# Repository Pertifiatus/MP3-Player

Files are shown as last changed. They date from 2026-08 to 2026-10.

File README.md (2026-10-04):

# MP3-Player

A compact **DIY music player**, smaller than an iPod Touch, built around a Raspberry Pi Compute Module 4 on a custom PCB. It syncs your **YouTube Music** library straight to the device, no home server needed.

## Concept

- **Front:** round GC9A01 display for menus and navigation
- **Back:** monochrome SSD1306 OLED for music visualizations
- **Audio:** mainly Bluetooth A2DP, plus a 3.5 mm headphone jack (ES8388 codec)
- **Controls:** button box (SX1509 GPIO expander) + IMU (QMI8658A) for orientation and shake gestures
- **Power:** Li-ion battery, USB-C charging (RT9466) with an 80% charge limit, fuel gauge (MAX17048), soft power button
- **Lighting:** SK6812 status ring

## Hardware

| Part | Details |
|---|---|
| Compute | Raspberry Pi CM4 Lite Wireless (boots from microSD), on 2× Hirose mezzanine connectors |
| Power | TPS63020 buck-boost, RT9466 charger, MAX17048 fuel gauge |
| Audio | ES8388 codec over I2S |
| Displays | GC9A01 (SPI0), SSD1306 (SPI4) |
| PCBs | Main board + ButtonBox, designed in KiCad (`KiCad/Projekt 1`) |
| Case | Fusion 360 (`CAD/Player.f3z`) |

## Software (`Software/`)

Python on Raspberry Pi OS, running as systemd services:

| File | Purpose |
|---|---|
| `main.py` | Main UI loop (front display, buttons, IMU) |
| `player.py` | Playback |
| `sync_youtube.py` | YouTube Music library sync |
| `connectivity.py` | WiFi / Bluetooth connections |
| `ui_state.py`, `ui_render.py` | UI state machine and rendering |
| `buttonbox.py`, `qmi8658.py`, `es8388.py`, `max17048.py`, `rt9466.py` | Hardware drivers |
| `charge_control.py`, `power_button.py` | Charging logic and soft shutdown |
| `led_control.py`, `led_service.py` | Status ring LEDs |
| `setup_pi.sh`, `*.service`, `sdcard-boot-*` | Pi setup and boot configuration |
| `test_*.py` | Tests |

## Status

Work in progress. Board 2 boots reliably; the software bring-up and debugging of battery operation are ongoing. Detailed notes on hardware, pinout, `config.txt` and lessons learned are in [`CLAUDE.md`](CLAUDE.md) and [`Software/NOTES_FOR_PER.md`](Software/NOTES_FOR_PER.md).

## Repository structure

```
CAD/        Fusion 360 case
KiCad/      Main board + ButtonBox (schematics, PCB, 3D models)
Software/   Python application, drivers, services, tests
docs/       Design specs and plans (status ring, quick connect)
```

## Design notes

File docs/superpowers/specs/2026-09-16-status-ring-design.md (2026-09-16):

# Status-Ring: Akku + WLAN/Bluetooth am Displayrand

## Ziel

Akkustand (%), WLAN- und Bluetooth-Status sollen am runden Front-Display sichtbar
sein, ohne bestehenden Screen-Inhalt zu verdecken. Bisher liest `main.py` den
MAX17048 (Fuel Gauge) gar nicht - nur der separate `charge_control.py`-Service tut
das für die Ladelogik. WLAN/BT-Status existiert bereits in `ui_state`/`connectivity.py`,
ist aber nur in den WLAN/BT-Menüs sichtbar, nicht auf einen Blick.

## Sichtbarkeit (Settings-Toggle)

Neuer Eintrag unter Settings → Anzeige: **"Statusanzeige"** (choice, wie
`display.led_mode`), Werte `"home"` (Standard) / `"always"`:
- `"home"`: Ring nur auf dem Homescreen.
- `"always"`: Ring auf jedem Screen.

Technisch macht das kaum einen Unterschied, da der Ring in einem Rand-Bereich liegt,
den kein bestehender Screen aktuell nutzt (siehe unten) - der Toggle existiert rein,
weil der Nutzer das explizit so wollte (z.B. falls der Ring auf dem Now-Playing-Screen
optisch stören sollte).

## Visuelles Design (auf dem Home-Browser-Mockup abgestimmt und freigegeben)

Alle Werte in der 240×240-Koordinate des echten Displays (nicht die gezoomte
320px-Mockup-Darstellung). Ursprung/Formel: `x = 120 + r·cos(θ)`, `y = 120 + r·sin(θ)`,
θ in Grad, steigendes θ läuft am Bildschirm im Uhrzeigersinn.

**Radius/Ring liegt fix bei r=110** (nicht `ui_scale`-abhängig, wie `SAFE_R` eine
Hardware-Konstante) - äußerer Rand des 12px-Strichs landet bei r=116, also ~4px
Abstand zum physischen Bezel-Rand (r=120). Innerer Rand bei r=104 = identisch mit
`SAFE_R`, kollidiert also nicht mit vorhandenem Safe-Area-Inhalt.

1. **Akku-Slot**: Bogen von θ=-55° bis θ=+30° (85° Spannweite), Strichbreite 12px,
   `round`-Linecap an beiden Enden (klassische Pill-/Slot-Form).
   - Track: dunkelgrau (`#3a3a3c`, passt zu `GROUP_BG`-Familie).
   - Fill: Akzentfarbe (`ACCENT` = `#31d1a6`), von θ=-55° bis zum
     ladungs-proportionalen Punkt innerhalb der 85°-Spanne.
2. **WLAN-Punkt**: Kreis bei θ=+38°, Radius 6px (= halbe Strichbreite, gleiche
   optische Dicke wie der Slot).
3. **Bluetooth-Punkt**: Kreis bei θ=+46°, Radius 6px.
   - Abstand Slot-Ende↔WLAN-Punkt und WLAN-Punkt↔BT-Punkt jeweils ~3px zwischen den
     sichtbaren Kanten (Rundungen mit eingerechnet).
4. **Prozent-Text**: klein (~11px Font), nahe der oberen Kante neben dem Slot-Anfang
   (Richtwert (183, 16), siehe Hinweis unten zur Feinjustage).

**Drei Zustände pro Punkt** (WLAN und Bluetooth gleich kodiert, nur Farbe
unterschiedlich - Weiß für WLAN, Blau (`#0a84ff`, passt zu `CATEGORY_COLORS["connectivity"]`)
für Bluetooth):
- **Aus**: gedimmt gefüllt (`#48484a`, wie `_draw_toggle_pill`s Aus-Farbe).
- **An, nicht verbunden**: hohler Ring (`stroke`, kein `fill`) in der jeweiligen Farbe.
- **Verbunden**: voll gefüllt in der jeweiligen Farbe.

## Bekannter Feinjustage-Punkt (bewusst nicht jetzt gelöst)

Der Home-Screen-Header ("MINI-MUSIKPLAYER", zentriert bei y=36, nur wenn
`home_sel == 0`) kann sich mit dem Prozent-Text/Slot-Anfang überschneiden, je
nachdem wie breit der letter-spaced Header mit den echten DejaVu-Fonts tatsächlich
rendert (auf Windows/Arial lokal nicht exakt prüfbar, siehe bestehende Einschränkung
in `NOTES_FOR_PER.md`). Wird beim ersten Live-Test auf echter Hardware geprüft und
falls nötig verschoben (z.B. Prozent-Text ein paar Pixel tiefer) - kein Blocker für
die Implementierung.

## Datenanbindung

### Akkustand (neu für `main.py`)
- `main.py` bekommt eine eigene `MAX17048`-Instanz (gleiches I2C-Gerät, das auch
  `charge_control.py` als separater Prozess nutzt - kurze Einzel-Reads sind
  bus-seitig unproblematisch, kein gemeinsamer State nötig).
- Poll-Intervall: alle 30s (SOC ändert sich langsam, kein Grund häufiger zu lesen,
  gleiches Prinzip wie `charge_control.py`s eigener Poll-Zyklus).
- Fehlerfall (Gauge nicht erreichbar): wie beim IMU in `main()` behandeln -
  `try/except`, Feature fällt auf "kein Ring-Update" zurück statt zu crashen.

### WLAN/Bluetooth-Status (bereits vorhanden, nur neu zusammengeführt)
- **An/Aus**: `state.settings.get("connectivity", "wifi"/"bluetooth")` - existiert
  bereits.
- **Verbunden**: leichte, gedrosselte Polls (kein Shell-Aufruf pro Frame):
  - WLAN: `connectivity.wifi_known_connections()`, `any(n["connected"] for n in ...)`.
  - Bluetooth: `connectivity.bluetooth_known_devices()`, analog.
  - Intervall: alle 10s, gleiches Muster wie die bestehenden
    `WIFI_REDRAW_INTERVAL`/`BT_REDRAW_INTERVAL`-Konstanten in `main.py`.

## Rendering-Integration

Ein neuer `_draw_status_ring(img, draw, state)` in `ui_render.py`, aufgerufen aus
dem zentralen `render()`-Dispatcher (nicht in jeder einzelnen `render_*`-Funktion
dupliziert) - abhängig von `state.settings.get("display", "status_ring")`:
`"always"` → nach jedem Screen zeichnen, `"home"` → nur wenn
`state.screen == ui_state.SCREEN_HOME`.

## Testing

Neue Fälle in `test_ui_render.py` (bestehendes Muster: alle Screens/States
durchrendern, `py_compile`-Smoke-Test): Ring bei 0%/50%/100% Akku und allen
3×3-Kombinationen WLAN/BT-Zustand rendern, keine Exception, Werte bleiben innerhalb
des 240×240-Bilds.

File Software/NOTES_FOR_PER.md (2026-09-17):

## TODO: LED-Indicator-Flash übergangsweise deaktiviert (17.09.2026)

Beim Durchgehen der LED-Settings festgestellt: `led_service.py` läuft aktuell
gar nicht auf dem Gerät (kein systemd-Unit, kein manueller Prozess) - die
LED-Einstellungen (An/Aus, Modus, Farbe, Helligkeit) schreiben zwar korrekt in
`settings.json`, steuern aber noch keine echte Hardware an. Bevor der Service
eingerichtet wird, kam eine wichtige Korrektur von Per: **aktuell sind nur 3
LEDs verkabelt**, nicht die ursprünglich angenommenen 9 (6 Hauptboard + 3
ButtonBox) - `led_control.NUM_LEDS` entsprechend auf 3 korrigiert. Mapping:
Index 0 = Play/Pause, 1 = Shuffle, 2 = Stop (je eine feste Pro-Button-LED, kein
generischer Streifen).

Dadurch hat `led_service.py`s Encoder-Skip/Volume-Cue (kurzer Farbblitz beim
Umschalten auf der Playing-Screen, ausgelöst über `main.py`s
`settings.set("led", "indicator", ...)`) keine LED mehr, die er benutzen
könnte - `INDICATOR_LED_INDEX = 4` lag schon für die alte 9er-Annahme am
oberen Rand, mit nur 3 LEDs (Index 0-2) ist er komplett out of range und hätte
beim ersten Auslösen gecrasht (`flash_indicator()` schreibt auf
`self._pixels[index]`).

**Übergangsweise auskommentiert** in `led_service.py` (`INDICATOR_LED_INDEX`
und der Aufruf von `flash_indicator()` in der Poll-Loop, mit `ponytail:`-
Kommentar an der Stelle) - `main.py` schreibt weiterhin harmlos in
`settings["led"]["indicator"]`, nur liest aktuell niemand mehr davon.

**TODO sobald mehr LEDs verlötet sind (oder eine der 3 bestehenden dafür
freigegeben wird):** Cue-Flash wieder aktivieren - entweder auf einer neuen,
freien LED-Nummer, oder bewusst auf einer der 3 Button-LEDs (z.B. Play/Pause,
da die während des Encoder-Drehens meist nicht gerade blinkt) mitlaufen lassen.
Nicht vergessen: `led_service.py` braucht sowieso noch einen echten
systemd-Unit (root, PWM+DMA) - bis dahin ist das ganze LED-Feature ohnehin nur
Settings-UI ohne sichtbare Wirkung.

## Nachtrag: UI-Groesse überarbeitet - echtes Reflow statt Zoom (12.09.2026, fünfter Durchgang)

Kein Pi-Zugriff, rein lokal (Windows) an `ui_render.py` gearbeitet + Logik-/Layout-
Smoketest (`test_ui_render.py`, neu) - **noch nicht auf echter Hardware/mit den
echten DejaVu-Fonts visuell verifiziert**, bitte beim nächsten Boot durch alle 5
UI-Groesse-Stufen auf Home/Bibliothek/Playlist/Settings klicken.

Auslöser: Feedback, dass "UI Scale" bisher nur pixelig rein-/rauszoomt statt bei
kleineren Stufen den gewonnenen Platz für mehr Inhalt zu nutzen, dass generell zu
viel Text abgeschnitten wird und dass die Ränder unnötig dick sind.

**Kompletter Umbau von `_apply_ui_scale`** (der alte Zoom-aufs-fertige-Bild-Ansatz,
siehe Nachtrag weiter unten - jetzt entfernt) **zu echter Layout-Skalierung**: Der
`scale`-Faktor fließt jetzt direkt in Fontgrößen, Row-Heights, Icon-Größen und
Innenabstände in `_render_nav_list`, `render_settings_detail` etc. ein, statt nur
das fertige 240×240-Bild zu croppen/skalieren. Effekt: bei kleiner UI-Groesse
passen durch kleinere Rows tatsächlich mehr Einträge in denselben runden Safe-Bereich
(gemessen: Playlist-Liste zeigt bei Stufe 1 eine dritte teilsichtbare Zeile, die bei
Stufe 3 nicht mehr da ist), bei größerer UI-Groesse werden Fonts/Rows größer
(besser lesbar), dafür passt weniger gleichzeitig auf den Screen - erwarteter
Trade-off, kein Bug. Fonts werden jetzt lazy per `(key, scale)` geladen und gecacht
(`ui_render._font`), nicht mehr als fixe Modul-Konstanten.

Nebenbei allgemein die Innenabstände verkleinert (Header-Padding, Icon/Text-Abstände
in den Listen, Settings-Card-Ränder), damit generell mehr vom runden Screen genutzt
wird, unabhängig von der UI-Groesse-Stufe. **SAFE_R (der physische Rundbezel-Wert)
wurde bewusst NICHT verändert** - das ist eine Hardware-Grenze, keine Stil-Vorgabe.

**Echter Bug beim Umbau gefunden und gefixt:** `render_settings_detail` ging bisher
davon aus, dass eine Settings-Kategorie immer komplett auf den Screen passt (stimmte
zufällig bei allen aktuellen Kategorien bei Stufe 3). Sobald Rows bei größeren
UI-Groesse-Stufen mitwachsen, ragte die Karte für Kategorien mit mehr Einträgen
(z.B. "LED", 4 Einträge) über den unteren Bildrand hinaus - `draw.rounded_rectangle`
crashte dabei sogar hart (`x1 must be greater than or equal to x0`), weil die Karte
an dem Punkt schon komplett außerhalb des runden Safe-Bereichs lag. Fix: die Liste
scrollt jetzt um die aktuelle Auswahl herum (gleiches Prinzip wie die Home/Bibliothek-
Listen), inkl. kleiner Auf/Ab-Pfeil-Indikatoren, wenn oben/unten noch mehr Einträge
verborgen sind. `test_ui_render.py` rendert alle Screens bei allen 5 Stufen durch und
hätte diesen Crash sofort gefangen.

`UI_SCALE_STEPS`-Werte dabei leicht verbreitert (0.75-1.3 statt 0.82-1.25), damit der
jetzt echte Skalierungseffekt sichtbarer ist. Stufe 3 bleibt exakt 1.0 = alle Pixel-
Konstanten im File wie ursprünglich getunt, unverändertes Verhalten für den Standard-
Fall.

---

## Nachtrag: ~1fps-Refresh + Encoder-Aussetzer (12.09.2026, vierter Durchgang)

Du warst kurz weg, ich hatte keinen Pi-Zugriff. Beides unten ist lokal
simuliert/getestet (reine Logik + Timing-Messung auf meinem Windows-Rechner) und
per Recherche im offiziellen Adafruit_Blinka_Displayio-Quellcode auf GitHub
abgesichert — **aber noch NICHT auf echter Hardware verifiziert**. Bitte beim
nächsten Boot beides gezielt gegentesten (Navigation durchklicken + Encoder in
beide Richtungen mehrfach drehen).

### 1fps-Fix: `push_frame()` → `FrameSink` in [main.py](main.py)

Root Cause gefunden, nicht nur vermutet: Ich habe den tatsächlichen Quellcode von
`Adafruit_Blinka_Displayio` auf GitHub geprüft. `displayio.OnDiskBitmap._get_pixel()`
liest **jeden einzelnen Pixel per eigenem Datei-`seek()`+`read()` vom Datenträger**,
und das passiert innerhalb der (ebenfalls reinem Python, pixel-für-pixel-Schleife)
Bildkomposition in `_tilegrid.py`. Die alte `push_frame()` hat bei **jedem** Redraw
ein komplett neues `OnDiskBitmap` aus einer frisch gespeicherten Datei gebaut — macht
bei 240×240 = 57.600 Pixel pro Frame theoretisch 57.600 Einzel-Dateizugriffe. Das
erklärt die ~1fps ziemlich genau (das reine `ui_render()` selbst braucht lokal
gemessen nur ~20ms/Frame, ist also nicht der Flaschenhals).

Fix: `FrameSink`-Klasse baut `Bitmap`/`TileGrid`/`Group` **einmalig** beim Start
(nicht mehr pro Frame neu), hält sie im RAM, und jeder Redraw schreibt die
RGB565-Pixel direkt in das bestehende `Bitmap` — kein Datei-Umweg mehr. Farbkonvertierung
RGB→RGB565 läuft vektorisiert über numpy (schnell), nur das eigentliche Schreiben in
den `Bitmap` läuft noch pixelweise über `bitmap[i] = value` (das ist die einzige
öffentlich dokumentierte Schreib-API, die ich im Quellcode bestätigt gefunden habe —
lokal gemessen ~5-7ms für 57.600 Pixel auf einem schnellen PC, auf dem CM4 evtl.
30-100ms, aber selbst das wäre um Größenordnungen schneller als der alte
Platten-Umweg).

**Falls es auf dem Pi immer noch spürbar hakt:** nächster Hebel wäre, `displayio`
für die Pixel-Übertragung ganz zu umgehen und die RGB565-Bytes direkt über den
SPI-Bus zu schreiben (wie z.B. `luma.lcd` es für andere Displays macht) — das ist ein
größerer Umbau, den ich nicht blind schreiben wollte ohne die aktuelle
Verbesserung erst mal live zu sehen.

### Encoder-Fix: Debounce-State-Machine in [buttonbox.py](buttonbox.py)

Die alte `_QUAD_TABLE`-Logik hat bei **jedem einzelnen Viertelschritt** gefeuert und
hatte keinerlei Prellschutz auf den Encoder-Leitungen (nur Buttons hatten
`DEBOUNCE_S`). Recherche dazu (siehe Quellenliste unten) bestätigt: genau das ist
eine bekannte Fehlerklasse bei I2C-gepollten Encodern — ein Prellen auf nur einer der
beiden Leitungen (A oder B) kann in der einfachen Tabelle als gültiger Übergang in
die **falsche** Richtung interpretiert werden, was zur gemeldeten
richtungsabhängigen Unzuverlässigkeit passt.

Neue Logik in `decode_encoder_step()`: läuft dem gültigen Gray-Code-Zyklus
(00→01→11→10→00) als Zähler entlang und feuert erst nach einem **vollständigen**,
in sich konsistenten 4-Schritt-Durchlauf (= ein Klick am Rastpunkt). Prellen
(Sprung zurück zum vorherigen Wert) und übersprungene Zwischenzustände (bei zu
langsamer Poll-Schleife) verwerfen jeweils nur den einen zweideutigen Schritt,
lösen aber keine Fehlauslösung mehr aus. Mit 8 Tests in
[test_buttonbox.py](test_buttonbox.py) durchgetestet (saubere CW/CCW-Klicks,
Prellen an verschiedenen Stellen der Sequenz, übersprungene Zustände) — alle grün.

**Nebeneffekt, bitte beachten:** Die alte Logik hat pro physischem Klick (4
Viertelschritte) theoretisch 4x ausgelöst, die neue genau 1x pro Klick. Falls sich
der Encoder jetzt "zu träge" anfühlt (mehr Drehung nötig pro Menüschritt als
gewohnt), sag mir das — dann justiere ich `DETENT_STEPS` in `buttonbox.py`.

Da der 1fps-Bug die komplette Poll-Schleife bei jedem Redraw für hunderte
Millisekunden blockiert hat, dürfte der FrameSink-Fix allein schon einen Großteil
der Encoder-Aussetzer beheben (verpasste Zwischenzustände durch zu seltenes
Pollen) — die Debounce-Fix behebt zusätzlich die richtungsabhängigen Fehlauslösungen
durch Prellen, die auch bei schneller Poll-Schleife noch auftreten könnten.

## Nachtrag: UI-Größe-Einstellung (11.09.2026, dritter Durchgang)

**Überholt, siehe Nachtrag ganz oben (12.09.2026, fünfter Durchgang)** - der
Zoom-Ansatz unten wurde durch echte Layout-Skalierung ersetzt. Als Historie
stehen gelassen.

Neuer Settings-Punkt unter Anzeige: "UI-Groesse" (Stepper 1-5, Standard 3=100%).
Implementiert als **Zoom aufs fertig gerenderte Bild** (`_apply_ui_scale` in
`ui_render.py`), nicht als Skalierung jeder einzelnen Pixelzahl im Code — deutlich
weniger Code, kein Risiko dass irgendwo eine feste Zahl vergessen wird und Elemente
überlappen. Trade-off: bei größeren Stufen wird das Bild reingezoomt (Ränder werden
abgeschnitten, wie bei jedem Digital-Zoom), bei kleineren rausgezoomt (schwarzer Rand
rundrum). Lokal bei allen 5 Stufen getestet, sieht sauber aus. Logik-Tests weiterhin
grün (nur ein neuer Settings-Eintrag, State-Machine sonst unverändert).

## Nachtrag: Apple/iOS-Redesign (11.09.2026, zweiter Durchgang)

Auf Wunsch komplett neuer visueller Look für `ui_render.py` (State-Machine/Logik
unverändert, nur die Optik):
- Echtes Schwarz als Hintergrund statt Dunkelgrau, iOS-System-Grau-Palette für Text
- Settings-Kategorien haben jetzt knallige, iOS-typische Icon-Farben (Anzeige=Orange,
  LED=Gelb, Verbindung=Blau, Sync=Türkis, Bewegung=Rot, Über=Grau) statt einheitlichem
  Grau
- Settings-Detail-Screens sind jetzt eine einzelne abgerundete Karte mit
  Trennlinien zwischen den Zeilen (iOS "Inset Grouped List"), statt einzelner Pillen
  pro Zeile
- Now-Playing hat jetzt einen echten Frosted-Glass-Effekt (geblurrter,
  abgedunkelter Ausschnitt hinter einer abgerundeten Pille) für die
  Play/Pause-Anzeige, statt nur freistehendem Text
- Icon-Badges sind jetzt "Squircle"-artig (großzügigerer Eckenradius) statt einfacher
  abgerundeter Quadrate

Alles wieder lokal gerendert + die 8 Logik-Tests laufen weiterhin durch (an der
State-Machine wurde nichts geändert). Gleiche Einschränkung wie vorher: nie auf
echter Hardware/DejaVu gesehen.

---

# Notizen zum UI/Interface-Ausbau (11.09.2026, während du weg warst)

Pi war die ganze Zeit aus — nichts davon ist auf echter Hardware getestet. Ich habe
alle Screens lokal mit PIL gerendert (Arial statt DejaVu als Ersatz-Font, da DejaVu
hier auf Windows nicht verfügbar war) um Layout/Lesbarkeit zu prüfen, und dabei ein
paar echte Bugs gefunden und gefixt (siehe unten). Alle Python-Dateien sind
syntax-geprüft (`py_compile`), aber der komplette Hardware-Pfad (Buttons, IMU, beide
Displays, LEDs) läuft zum ersten Mal beim nächsten Boot — bitte Schritt für Schritt
testen, nicht direkt alles auf einmal.

## Neue/geänderte Dateien in `Software/`

| Datei | Zweck |
|---|---|
| `ui_state.py` | State Machine: Home, Bibliothek, Playlist, Now-Playing, Settings (Kategorien + Detail), Sync-Login, Sync-Progress |
| `ui_render.py` | PIL-Rendering für alle Screens, inkl. rotierender Cover-Art-Platte mit Tonarm |
| `main.py` | Event-Loop: ButtonBox + IMU (Bewegungs-Features) + Display |
| `qmi8658.py` | IMU-Treiber als wiederverwendbares Modul (vorher nur Einweg-Testskript) |
| `led_control.py` | SK6812-Ansteuerung (Presets, Modi) |
| `led_service.py` | **Separater** root-Prozess, der `settings.json` beobachtet und die LEDs ansteuert |
| `settings.py` | Persistente Einstellungen (JSON-Datei) |
| `sync_youtube.py` | YouTube-Device-Flow-Login (echt implementiert) + simulierter Sync (Platzhalter) |

## Was garantiert noch nicht getestet ist — bitte in dieser Reihenfolge

1. **`python3 main.py` auf dem Pi starten** (braucht laufendes Front-Display + ButtonBox +
   QMI8658A — alles einzeln schon mal verifiziert, aber nie zusammen in einer Schleife).
2. Falls Fehler beim Start: `adafruit-blinka` + `adafruit-circuitpython-neopixel` sind
   evtl. noch nicht installiert (`pip3 install --break-system-packages
   adafruit-circuitpython-neopixel`) — nur für `led_control.py`/`led_service.py` nötig,
   `main.py` selbst importiert das nicht direkt.
3. `led_service.py` **braucht `sudo`** (PWM/DMA für die LEDs) — separat testen:
   `sudo python3 led_service.py`, dann in `settings.json` `led.enabled` auf `true`
   setzen und schauen ob die LEDs reagieren.

## Bewusste Design-Entscheidungen (getroffen, nicht mehr offen)

- **Stop-Taste = "Zurück"** in allen Menüs, zusätzlich "echtes Stop" (setzt Now-Playing
  zurück auf Home) wenn man sie im Now-Playing-Screen drückt.
- **Encoder-Drehen im Now-Playing-Screen = Track vor/zurück** (nicht Lautstärke — dafür
  gibt's aktuell keinen dedizierten Regler, siehe offene Frage unten).
- **Settings sind in 6 Kategorien** (Anzeige, LED, Verbindung, Sync, Bewegung, Über)
  organisiert, nicht eine lange flache Liste — bei einem 240px-Rundbildschirm sonst
  schnell unübersichtlich.
- **Icons als Buchstaben-Badges** (A/L/V/S/B/i) statt Symbol-Glyphen für die
  Settings-Kategorien — ich hatte erst Unicode-Symbole (☀ ✦ ⚡ ↻ ↕ ℹ) probiert, aber
  mehrere davon fehlen sogar in Arial (einem sehr breit unterstützten Font). Nur ♪
  und ⚙ sind aus einem früheren Live-Test auf dem echten Pi/DejaVu bestätigt sicher,
  alles andere Risiko wurde durch ASCII/Buchstaben ersetzt. **Bitte beim ersten Live-Test
  trotzdem kurz schauen ob irgendwo ein Kästchen (☐) statt einem Zeichen auftaucht** —
  falls ja, sag mir wo, dann tausche ich das gezielt aus.
- **Sync-Backend ist simuliert** (`sync_youtube.sync_library()` erzeugt Fake-Fortschritt
  über 8 Demo-Tracks) — die UI drumherum (Fortschrittsbalken, TV-Code-Screen) ist aber
  vollständig fertig und funktional, nur der eigentliche Download/ytmusicapi/yt-dlp/ffmpeg-Teil
  fehlt noch (siehe "Braucht deine Mitarbeit" unten).
- **LED-Kette läuft als separater root-Prozess** (`led_service.py`), nicht im
  Haupt-UI-Skript — vermeidet, dass die ganze UI (Display/Buttons/IMU) als root laufen
  muss, nur weil die LEDs PWM+DMA-Zugriff brauchen.

## Bewegungssensor-Features ("coole Sachen" mit dem Accelerometer)

Umgesetzt (in `main.py` / `apply_motion_features`):
- **Schütteln = Shuffle**: kräftige Bewegung (|Beschleunigung| > 2.2g) während
  Now-Playing überspringt zufällig vor/zurück und aktiviert die Shuffle-Anzeige.
- **Umdrehen = Pause**: wenn `orientation()` "z-" liefert (siehe Achsen-Warnung unten)
  und gerade etwas läuft, wird automatisch pausiert.

**Nicht umgesetzt, nur als Setting vorhanden (tut noch nichts):**
- **Auto-Display-Wechsel** (vorne/hinten je nach Ausrichtung) — der Setting-Toggle
  existiert in den Einstellungen, ist aber noch nicht verdrahtet. Grund: das würde
  bedeuten, das Rück-Display (SSD1306/luma) aus derselben Event-Loop wie das
  Front-Display zu steuern — das ist eine echte Architektur-Erweiterung
  (zwei Displays gleichzeitig koordinieren), die ich nicht blind bauen wollte ohne
  das live zu sehen. Wenn du zurück bist, können wir das als nächsten Schritt angehen.

**⚠️ Wichtig — Achsen-Mapping ist geraten, nicht verifiziert:** `orientation()` in
`qmi8658.py` gibt einfach die Achse zurück, die am nächsten an ±1g liegt (z.B. "z-").
Ich weiß nicht, welche physische Seite (vorne/hinten) das tatsächlich bedeutet — das
hängt davon ab, wie der QMI8658A-Chip auf der Platine liegt. **Bitte beim ersten Test:
Board flach hinlegen (Vorderseite nach oben), `python3 qmi8658.py` laufen lassen und
schauen welche Achse/Vorzeichen ausgegeben wird, dann das Gleiche mit Rückseite nach
oben — danach sag mir die beiden Werte, dann stelle ich `"z-"` in `apply_motion_features`
korrekt ein** (aktuell nur geraten, könnte auch falsch rum sein oder eine andere Achse
sein).

## Fragen, die ich nicht beantworten konnte (brauchen deine Entscheidung)

1. **LED-Kettenlänge:** `led_control.py` geht von 9 LEDs aus (6 Hauptplatine + 3
   ButtonBox, angenommen in Reihe). Nicht anhand des PCB-Layouts verifiziert — falls
   falsch, `NUM_LEDS` in `led_control.py` anpassen.
2. **SK6812MINI-E: RGB oder RGBW?** Ich bin von reinem RGB ausgegangen (Standard für
   die "MINI-E"-Variante). Falls es tatsächlich RGBW ist, braucht `neopixel.NeoPixel(...)`
   einen zusätzlichen `pixel_order=neopixel.GRBW`-Parameter.
3. **Lautstärke-Regelung:** Es gibt aktuell keinen UI-Weg die Lautstärke zu ändern
   (Encoder ist für Track-Skip belegt). Optionen für später: langes Drücken des
   Encoders = Lautstärke-Modus, oder ein Settings-Eintrag, oder Shuffle-Taste
   umwidmen. Sag mir was du willst.
4. **Auto-Sleep-Verhalten:** Der Settings-Eintrag "Auto-Aus" (Display-Standby nach
   X Sekunden Inaktivität) existiert als Einstellung, ist aber in `main.py` noch
   nicht tatsächlich verdrahtet (Backlight wird nirgends automatisch ausgeschaltet).
   Soll das den Backlight-Pin einfach dimmen/ausschalten, oder den ganzen
   Displayinhalt auf schwarz setzen?

## YouTube-Sync / TV-Setup — was noch fehlt

`sync_youtube.py` implementiert den **echten** Google-OAuth-Device-Flow (der
Standard-Mechanismus für TV/Limited-Input-Geräte: Code + URL anzeigen, User gibt den
Code auf Handy/PC ein, wir pollen bis bestätigt). Das ist kein Fake — das ist echtes,
funktionierendes Protokoll, sobald du Zugangsdaten hast.

**Was du dafür brauchst, bevor das erste Mal ein echter Login klappt:**
1. In der Google Cloud Console ein Projekt anlegen.
2. OAuth-Consent-Screen einrichten (reicht im "Testing"-Modus für privaten Gebrauch).
3. "YouTube Data API v3" aktivieren.
4. Unter Credentials einen OAuth-Client vom Typ **"TVs and Limited Input devices"**
   anlegen.
5. Die `client_id`/`client_secret` in eine neue Datei `Software/youtube_credentials.json`
   eintragen (Format steht im Docstring von `sync_youtube.py` oben) — **diese Datei
   NICHT committen**, sie ist noch nicht in `.gitignore`, das sollte ich/du noch
   ergänzen sobald die Datei existiert.

**Danach fehlt noch (nicht implementiert, nur die UI-Hülle steht):**
- Echte Bibliotheks-Abfrage über `ytmusicapi` (aktuell nicht mal als pip-Paket
  installiert).
- Download über `yt-dlp` + Remux über `ffmpeg`.
- Der WLAN/Metered-Check in `wifi_ok_for_sync()` ist aktuell ein Stub der immer
  `True` zurückgibt — müsste die echte Heim-SSID kennen und `nmcli` abfragen.

Das ist bewusst so gelassen — echtes Downloaden ohne deine OAuth-Zugangsdaten kann ich
eh nicht testen, aber die komplette UI drumherum (Code anzeigen, auf Bestätigung
warten, Fortschrittsbalken) ist fertig und sollte schon mit den echten Zugangsdaten
funktionieren, auch ohne dass der eigentliche Download-Teil schon existiert.

## Kleinere Bugs, die der lokale Test aufgedeckt hat (schon gefixt)

- `_render_nav_list` griff über einen privaten PIL-internen Pfad (`draw._image`) auf
  das Bild zu, um Cover-Art einzufügen — sauber gefixt, `img` wird jetzt explizit
  durchgereicht.
- Zwei Aufrufstellen von `_render_nav_list` hatten die alte Funktionssignatur nach
  einer Änderung nicht mitbekommen (`render_settings_root` u.a.) — hätte beim ersten
  Öffnen der Einstellungen sofort einen Crash gegeben.
- Lange Titel/Untertitel liefen über den Bildschirmrand hinaus statt abgeschnitten zu
  werden — Ellipsis-Kürzung ergänzt (wie im `beispiel.html`-Original).
- `state.shuffle` wurde in `ui_render.py` referenziert aber nie in `UIState.__init__`
  deklariert — hätte beim ersten Now-Playing-Aufruf gecrasht.

## Nicht getestet, aber nicht offensichtlich riskant

- Die hier vorhergesagte Performance-Sorge zum BMP-Datei-Umweg hat sich bestätigt
  (~1fps live gemeldet) — siehe "Nachtrag: ~1fps-Refresh + Encoder-Aussetzer" ganz
  oben in dieser Datei für Root Cause + Fix.

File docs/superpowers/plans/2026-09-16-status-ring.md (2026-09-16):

# Status-Ring (Akku + WLAN/Bluetooth) Implementation Plan

> **For agentic workers:** REQUIRED SUB-SKILL: Use superpowers:subagent-driven-development (recommended) or superpowers:executing-plans to implement this plan task-by-task. Steps use checkbox (`- [ ]`) syntax for tracking.

**Goal:** Show battery %, WLAN status and Bluetooth status as a ring hugging the round front-display's outer bezel margin, controllable via a new Settings toggle (Home-only vs. every screen).

**Architecture:** A pure-rendering function (`ui_render._draw_status_ring`) draws the ring onto whatever image `ui_render.render()` already produced, using three new plain fields on `UIState` (`battery_pct`, `wifi_connected`, `bt_connected`) that `main.py` refreshes on a slow poll cycle (30s battery, 10s WLAN/BT), mirroring the existing throttled-poll pattern already used for motion/BT/WiFi redraws in `main.py`.

**Tech Stack:** Python 3, PIL/Pillow (`ImageDraw.arc`/`ellipse`), existing `max17048.MAX17048` + `connectivity.py` drivers.

## Global Constraints

- Spec: `docs/superpowers/specs/2026-09-16-status-ring-design.md` - all pixel constants below (radius, angles, colors) are copied verbatim from there.
- The ring does **not** scale with `ui_scale` (fixed hardware-margin element, same reasoning as `ui_render.SAFE_R`).
- No new pip dependencies - only stdlib `math` (already imported in `ui_render.py`) and the existing `max17048`/`connectivity` modules.
- Every new pure-logic/rendering piece gets a test runnable with `python3 test_*.py` on a normal dev machine (no hardware) - matches this project's existing convention (see `test_ui_state.py`, `test_ui_render.py`). `main.py`'s hardware-loop wiring itself has no existing tests anywhere in this codebase (confirmed: no `test_main.py`) - that task ends in a manual on-device verification instead, consistent with how every other `main.py` change in this project's history (see `Software/NOTES_FOR_PER.md`) was verified.

---

### Task 1: "Statusanzeige" setting + visibility rule

**Files:**
- Modify: `Software/settings.py:7-12` (add default)
- Modify: `Software/ui_state.py` (add `SETTINGS_ITEMS["display"]` entry + `UIState.status_ring_visible()`)
- Test: `Software/test_ui_state.py`

**Interfaces:**
- Consumes: `Settings.get`/`Settings.set` (existing, unchanged), `UIState.screen`, `ui_state.SCREEN_HOME` (existing).
- Produces: `UIState.status_ring_visible(self) -> bool` - used by Task 2's `ui_render.render()` and Task 3's `main.py` dirty-flag logic.

- [ ] **Step 1: Write the failing test**

Add to `Software/test_ui_state.py` (near `test_choice_cycles`, same style):

```python
def test_status_ring_visible_depends_on_setting_and_screen():
    s = make_state()
    s.settings.set("display", "status_ring", "home")
    s.screen = ui_state.SCREEN_HOME
    assert s.status_ring_visible()
    s.screen = ui_state.SCREEN_LIBRARY
    assert not s.status_ring_visible()

    s.settings.set("display", "status_ring", "always")
    assert s.status_ring_visible()
    s.screen = ui_state.SCREEN_HOME
    assert s.status_ring_visible()

def test_status_ring_setting_cycles_via_settings_detail():
    s = make_state()
    s.settings.set("display", "status_ring", "home")
    s.settings_category = "display"
    idx = next(i for i, it in enumerate(ui_state.SETTINGS_ITEMS["display"]) if it["key"] == "status_ring")
    s.settings_detail_sel = idx
    s.settings_detail_activate()
    assert s.settings.get("display", "status_ring") == "always"
    s.settings_detail_activate()
    assert s.settings.get("display", "status_ring") == "home"
```

- [ ] **Step 2: Run test to verify it fails**

Run: `cd Software && python3 test_ui_state.py`
Expected: `AttributeError: 'UIState' object has no attribute 'status_ring_visible'` (or `KeyError: 'status_ring'` if it gets that far first)

- [ ] **Step 3: Add the setting default**

In `Software/settings.py`, inside `DEFAULTS["display"]` (currently lines 8-12):

```python
    "display": {
        "brightness": 3,     # 1-5, drives GC9A01 backlight PWM (GPIO13)
        "auto_sleep_s": 30,  # 0 = never sleep
        "ui_scale": 3,       # 1-5, index into ui_render.UI_SCALE_STEPS
        "status_ring": "home",  # "home" or "always" - see ui_render._draw_status_ring
    },
```

- [ ] **Step 4: Add the declarative settings-menu entry and the visibility method**

In `Software/ui_state.py`, inside `SETTINGS_ITEMS["display"]` (the list that currently ends with the `auto_sleep_s` choice entry), append:

```python
        {"key": "status_ring", "label": "Statusanzeige", "type": "choice",
         "choices": [("home", "Nur Home"), ("always", "Ueberall")]},
```

Add a method on `UIState` (near the other small helpers, e.g. right after `toggle_encoder_mode`'s class or anywhere inside `class UIState:` - place it right after `__init__`):

```python
    def status_ring_visible(self):
        return self.settings.get("display", "status_ring") == "always" or self.screen == SCREEN_HOME
```

- [ ] **Step 5: Run test to verify it passes**

Run: `cd Software && python3 test_ui_state.py`
Expected: `... 23 tests passed` (one more than the previous count - all `OK`, no failures)

- [ ] **Step 6: Commit**

```bash
git add Software/settings.py Software/ui_state.py Software/test_ui_state.py
git commit -m "Add Statusanzeige (status-ring visibility) setting"
```

---

### Task 2: `_draw_status_ring` rendering + dispatcher integration

**Files:**
- Modify: `Software/ui_state.py` (three new `UIState.__init__` fields)
- Modify: `Software/ui_render.py` (new constants, `_ring_point`, `_draw_status_dot`, `_draw_status_ring`, `render()` change)
- Test: `Software/test_ui_render.py`

**Interfaces:**
- Consumes: `UIState.status_ring_visible()` (Task 1), `UIState.settings.get("connectivity", "wifi"/"bluetooth")` (existing), `ui_render.ACCENT`/`TEXT`/`DIM`/`CATEGORY_COLORS` (existing), `ui_render._text_centered`/`_font` (existing).
- Produces: `UIState.battery_pct` (float 0-100 or `None`), `UIState.wifi_connected` / `UIState.bt_connected` (bool) - Task 3 sets these from real hardware polls. `ui_render._draw_status_ring(draw, state)` - not called directly by Task 3, only indirectly via `ui_render.render()`.

- [ ] **Step 1: Write the failing test**

Add to `Software/test_ui_render.py` (new top-level test function, same file, same style as `test_all_screens_render_at_every_scale`):

```python
def test_status_ring_renders_without_crashing():
    for battery_pct in (None, 0, 1, 50, 100, 104):  # 104: gauge over-reads slightly past 100, see max17048.py
        for wifi_on, wifi_connected in ((False, False), (True, False), (True, True)):
            for bt_on, bt_connected in ((False, False), (True, False), (True, True)):
                s = make_state()
                s.battery_pct = battery_pct
                s.wifi_connected = wifi_connected
                s.bt_connected = bt_connected
                s.settings.set("connectivity", "wifi", wifi_on)
                s.settings.set("connectivity", "bluetooth", bt_on)

                s.settings.set("display", "status_ring", "home")
                _assert_frame(ui_render.render(s))  # SCREEN_HOME - ring drawn

                s.screen = ui_state.SCREEN_LIBRARY
                _assert_frame(ui_render.render(s))  # "home" mode, not home - ring skipped

                s.settings.set("display", "status_ring", "always")
                _assert_frame(ui_render.render(s))  # "always" mode - ring drawn on library too
```

- [ ] **Step 2: Run test to verify it fails**

Run: `cd Software && python3 test_ui_render.py`
Expected: `AttributeError: 'UIState' object has no attribute 'battery_pct'` (test file sets it before first render, so this fires immediately)

- [ ] **Step 3: Add the three state fields**

In `Software/ui_state.py`, inside `UIState.__init__`, right after the existing `self.imu = None` line:

```python
        self.battery_pct = None  # 0-100 or None (gauge unavailable/not yet read); set by main.py from MAX17048
        self.wifi_connected = False  # set by main.py from connectivity.wifi_known_connections()
        self.bt_connected = False  # set by main.py from connectivity.bluetooth_known_devices()
```

- [ ] **Step 4: Run test to verify it now fails later (rendering not implemented yet)**

Run: `cd Software && python3 test_ui_render.py`
Expected: passes through field access now, but `render()` itself doesn't yet call any ring code, so this actually **passes already at this point** (nothing crashes - `render()` doesn't touch the new fields yet). That's expected: this step only proves the state fields exist. The ring behavior (mode="home" hides on Library) isn't asserted by pixel content in this test, only crash-freedom, so it can't fail here - proceed to Step 5 regardless.

- [ ] **Step 5: Implement `_draw_status_ring` and wire it into `render()`**

In `Software/ui_render.py`, add these module-level constants right after the existing `SAFE_R = 104` block (after `CARD_MAX_Y`'s definition, before `_header`):

```python
# --- status ring (battery + WLAN/BT) -----------------------------------------
# Fixed hardware-margin element, like SAFE_R - does NOT scale with ui_scale.
# Sits between SAFE_R (104) and the physical bezel (r=120): outer edge at
# RING_R + RING_WIDTH/2 = 116, ~4px from the true edge; inner edge at
# RING_R - RING_WIDTH/2 = 104, flush with SAFE_R. See
# docs/superpowers/specs/2026-09-16-status-ring-design.md for the layout this
# was tuned against.
RING_R = 110
RING_WIDTH = 12
RING_START_DEG = -55
RING_END_DEG = 30
WIFI_DOT_DEG = 38
BT_DOT_DEG = 46
DOT_R = 6
RING_TRACK = (58, 58, 60)
RING_OFF = (72, 72, 76)  # matches _draw_toggle_pill's "off" fill

def _ring_point(deg, r=RING_R):
    rad = math.radians(deg)
    return (W / 2 + r * math.cos(rad), W / 2 + r * math.sin(rad))

def _draw_status_dot(draw, deg, color, on, connected):
    x, y = _ring_point(deg)
    box = [x - DOT_R, y - DOT_R, x + DOT_R, y + DOT_R]
    if connected:
        draw.ellipse(box, fill=color)
    elif on:
        draw.ellipse(box, outline=color, width=2)
    else:
        draw.ellipse(box, fill=RING_OFF)

def _draw_status_ring(draw, state):
    bbox = [W / 2 - RING_R, W / 2 - RING_R, W / 2 + RING_R, W / 2 + RING_R]

    # track (empty slot), rounded ends - PIL's arc() has flat ends, so the caps
    # are faked with small filled circles at both endpoints (a stroke-linecap
    # of "round" is exactly a semicircle of radius=width/2 at the endpoint;
    # a full circle there looks identical since the arc itself covers the rest)
    draw.arc(bbox, RING_START_DEG, RING_END_DEG, fill=RING_TRACK, width=RING_WIDTH)
    for deg in (RING_START_DEG, RING_END_DEG):
        x, y = _ring_point(deg)
        draw.ellipse([x - DOT_R, y - DOT_R, x + DOT_R, y + DOT_R], fill=RING_TRACK)

    if state.battery_pct is not None:
        pct = max(0, min(100, round(state.battery_pct)))
        if pct > 0:
            fill_end = RING_START_DEG + (RING_END_DEG - RING_START_DEG) * pct / 100
            draw.arc(bbox, RING_START_DEG, fill_end, fill=ACCENT, width=RING_WIDTH)
            for deg in (RING_START_DEG, fill_end):
                x, y = _ring_point(deg)
                draw.ellipse([x - DOT_R, y - DOT_R, x + DOT_R, y + DOT_R], fill=ACCENT)
        # anchored inward (r=85, well inside SAFE_R) so it can never land outside
        # the physical bezel regardless of font metrics - exact position vs. the
        # Home header may still need live tuning, see the spec's known-follow-up note
        text_x, text_y = _ring_point(RING_START_DEG, r=85)
        _text_centered(draw, text_x, text_y, f"{pct}%", _font("ring_pct", 1.0), DIM)

    _draw_status_dot(draw, WIFI_DOT_DEG, TEXT, state.settings.get("connectivity", "wifi"), state.wifi_connected)
    _draw_status_dot(draw, BT_DOT_DEG, CATEGORY_COLORS["connectivity"],
                      state.settings.get("connectivity", "bluetooth"), state.bt_connected)
```

Add the new font to `FONT_FILES` (the dict defined around line 52-66), inserting after `"header"`:

```python
    "ring_pct": (FONT_DIR + "DejaVuSans-Bold.ttf", 11),
```

Finally, change `render()` at the bottom of the file from:

```python
def render(state: ui_state.UIState) -> Image.Image:
    return _RENDERERS[state.screen](state)
```

to:

```python
def render(state: ui_state.UIState) -> Image.Image:
    img = _RENDERERS[state.screen](state)
    if state.status_ring_visible():
        _draw_status_ring(ImageDraw.Draw(img), state)
    return img
```

- [ ] **Step 6: Run test to verify it passes**

Run: `cd Software && python3 test_ui_render.py`
Expected: `... N tests passed` (all `OK`, no failures/exceptions)

- [ ] **Step 7: Commit**

```bash
git add Software/ui_state.py Software/ui_render.py Software/test_ui_render.py
git commit -m "Render battery/WLAN/Bluetooth status ring on the front display"
```

---

### Task 3: `main.py` wiring - real battery/connectivity polling

**Files:**
- Modify: `Software/main.py`

**Interfaces:**
- Consumes: `max17048.MAX17048().read_soc_pct()` (existing, unchanged), `connectivity.wifi_known_connections()` / `connectivity.bluetooth_known_devices()` (existing, unchanged), `UIState.status_ring_visible()` (Task 1), `UIState.battery_pct`/`wifi_connected`/`bt_connected` (Task 2).
- Produces: nothing consumed by a later task - this is the final integration point.

No unit test exists for `main.py`'s hardware loop anywhere in this codebase (it drives real GPIO/I2C/SPI) - verification is manual, on the actual Pi, same as every other `main.py` change documented in `Software/NOTES_FOR_PER.md`.

- [ ] **Step 1: Add the import and poll-interval constants**

In `Software/main.py`, add to the imports (near the other `from X import Y` lines, after `from qmi8658 import ...`):

```python
from max17048 import MAX17048
```

Add two constants next to the existing `*_INTERVAL` constants near the top of the file (after `SYNC_REDRAW_INTERVAL`):

```python
BATTERY_POLL_INTERVAL = 30  # SOC changes slowly - no reason to hit I2C more often
STATUS_POLL_INTERVAL = 10  # WLAN/BT "connected" check - cheap nmcli/bluetoothctl queries, no scan involved
```

- [ ] **Step 2: Construct the gauge alongside the IMU**

In `main()`, right after the existing IMU try/except block:

```python
    try:
        state.imu = QMI8658()
    except Exception as e:
        print(f"QMI8658A nicht verfuegbar, Bewegungs-Features deaktiviert: {e}")
        state.imu = None
```

add:

```python
    try:
        battery_gauge = MAX17048()
    except Exception as e:
        print(f"MAX17048 nicht verfuegbar, Akkustand-Anzeige deaktiviert: {e}")
        battery_gauge = None
```

- [ ] **Step 3: Initialize the poll clocks**

Next to the existing `last_*` initializations (`last_playing_redraw`, `last_motion_poll`, etc.), add:

```python
    last_battery_poll = time.monotonic()
    last_status_poll = time.monotonic()
```

- [ ] **Step 4: Poll and mark dirty on change**

In the main `while True:` loop, right after the existing motion-poll block:

```python
        if state.imu is not None and now - last_motion_poll >= MOTION_POLL_INTERVAL:
            last_motion_poll = now
            if apply_motion_features(state):
                dirty = True
```

add:

```python
        if battery_gauge is not None and now - last_battery_poll >= BATTERY_POLL_INTERVAL:
            last_battery_poll = now
            try:
                new_pct = round(battery_gauge.read_soc_pct())
            except OSError:
                new_pct = state.battery_pct  # transient I2C hiccup - keep the last known value
            if new_pct != state.battery_pct:
                state.battery_pct = new_pct
                if state.status_ring_visible():
                    dirty = True

        if now - last_status_poll >= STATUS_POLL_INTERVAL:
            last_status_poll = now
            new_wifi_connected = any(n["connected"] for n in connectivity.wifi_known_connections())
            new_bt_connected = any(d["connected"] for d in connectivity.bluetooth_known_devices())
            if new_wifi_connected != state.wifi_connected or new_bt_connected != state.bt_connected:
                state.wifi_connected = new_wifi_connected
                state.bt_connected = new_bt_connected
                if state.status_ring_visible():
                    dirty = True
```

- [ ] **Step 5: Syntax-check locally (no hardware needed for this much)**

Run: `cd Software && python3 -c "import py_compile; py_compile.compile('main.py', doraise=True); print('OK')"`
Expected: `OK`

- [ ] **Step 6: Commit**

```bash
git add Software/main.py
git commit -m "Poll MAX17048 + WLAN/BT connection state for the status ring"
```

- [ ] **Step 7: Deploy to the Pi and verify live**

```bash
KEY=~/.ssh/id_ed25519_mp3player
HOST=pkenner@192.168.188.108
scp -i "$KEY" Software/settings.py Software/ui_state.py Software/ui_render.py Software/main.py "$HOST:/tmp/"
ssh -i "$KEY" "$HOST" "cp /tmp/{settings,ui_state,ui_render,main}.py ~/mp3player/ && rm /tmp/{settings,ui_state,ui_render,main}.py"
ssh -i "$KEY" "$HOST" "sudo systemctl restart mp3player.service"
```

Then, looking at the actual front display:
- Home screen shows the ring: gray-to-teal battery slot on the right edge with a `NN%` label near the top, a white WLAN dot, a blue-ish Bluetooth dot.
- Toggle "Statusanzeige" in Settings → Anzeige between "Nur Home" and "Ueberall"; confirm the ring disappears/appears on Library/Now-Playing accordingly.
- Toggle WLAN/Bluetooth off in Settings → Verbindung; confirm the corresponding dot goes from filled to dimmed within ~10s.
- Check whether the `NN%` label collides with the "MINI-MUSIKPLAYER" home header (the known open point from the spec) - if it does, nudge `text_x, text_y = _ring_point(RING_START_DEG, r=85)` in `ui_render._draw_status_ring` (e.g. a smaller `r` moves it further from the edge) and re-deploy.

If the label/header collide or spacing looks off on the real DejaVu fonts, fix the constants directly in `Software/ui_render.py`, redeploy, and commit the fix as its own follow-up commit (`git commit -m "Tune status-ring percentage label position after live check"`) - matches how every other pixel-tuning pass in this project's history was done (see `Software/NOTES_FOR_PER.md`).

---

## Self-Review Notes

- **Spec coverage:** Settings toggle (Task 1), ring visuals/3-state dots/percentage text (Task 2), MAX17048 + connectivity polling with the documented intervals (Task 3), known header-collision follow-up carried into Task 3's manual-verify step. All spec sections covered.
- **Placeholders:** none - every step has complete, runnable code.
- **Type/name consistency checked:** `status_ring_visible()` (Task 1) is the exact name used by both `ui_render.render()` (Task 2) and `main.py` (Task 3). `battery_pct`/`wifi_connected`/`bt_connected` (Task 2 field names) are the exact names Task 3 assigns to. `RING_START_DEG`/`RING_END_DEG`/`RING_R`/`DOT_R` are defined once in Task 2 and not redefined elsewhere.

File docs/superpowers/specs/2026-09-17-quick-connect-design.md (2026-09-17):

# Quick Connect: Play/Pause halten im Hauptmenü

## Ziel

Vom Homescreen aus per gehaltenem Play/Pause-Button (ButtonBox) direkt mit den
zuletzt verbundenen Bluetooth-Kopfhörern verbinden und den zuletzt gespielten
Song fortsetzen - ohne den Umweg über Einstellungen → Verbindung → Bluetooth.

## Auslöser & Ablauf

Nur auf `SCREEN_HOME` aktiv (Play/Pause hat dort sonst keine Funktion, also
keine Kollision mit bestehendem Verhalten):

1. **Play/Pause gedrückt halten** → sofort erscheint ein Ring-Overlay über dem
   Homescreen: dünner grauer Kreis-Umriss, darüber der Text "Quick Connect".
   Der Bereich dahinter wird abgedunkelt (gleiches Crop+Blend+Masken-Verfahren
   wie `_frosted_pill`, nur mit Kreismaske statt Rounded-Rect) für Lesbarkeit.
2. **Weiter halten** → ein weißer Bogen wächst von oben (12 Uhr) im
   Uhrzeigersinn und schließt sich nach **2 Sekunden** zum Vollkreis.
3. **Vor Ablauf losgelassen** → Ring verschwindet sofort, keine weitere Aktion
   (wie ein normaler Home-Screen).
4. **Ring komplett gefüllt** → Verbindungsversuch startet automatisch (Loslassen
   des Buttons spielt ab hier keine Rolle mehr):
   - Fehlt entweder ein bekanntes "zuletzt verbundenes" Bluetooth-Gerät oder
     ein zuletzt gespielter Song (`last_played`), bricht sofort ab: Ring bleibt
     kurz (~1,5s) als Vollkreis stehen, Text wechselt zu einer kurzen
     Fehlermeldung ("Kein Gerät" / "Kein Song") in Rot, dann verschwindet der
     Ring wieder.
   - Sonst: Ring bleibt Vollkreis stehen, Text wechselt zu "Verbinde...",
     `bluetoothctl connect <mac>` läuft im Hintergrund (wie bestehender
     `BTWorker`, blockiert nicht die Render-Loop).
     - Erfolg: sofortiger Wechsel zum Now-Playing-Screen mit dem zuletzt
       gespielten Song (identisches Verhalten zum bestehenden "Fortsetzen"-
       Eintrag auf dem Homescreen), Ring verschwindet.
     - Fehler (Timeout/Ablehnung): gleiche Fehleranzeige wie oben, mit der
       tatsächlichen Fehlermeldung von `connectivity.bluetooth_connect()`.

## "Zuletzt verbundenes Gerät"

Existiert aktuell nirgends als Konzept - `bluetooth_known_devices()` liefert
nur *alle* getrauten Geräte plus aktuellen Verbindungsstatus, keine Historie.
Neu: `settings.json` bekommt `connectivity.last_bt_device` (MAC oder `None`),
geschrieben an den beiden Stellen, an denen `main.py` heute schon eine
erfolgreiche Verbindung herstellt: `BTWorker._device_action("connect", mac)`
und `BTWorker._pair(mac)` (pairing verbindet laut `bluetooth_pair()`-Docstring
ohnehin gleich mit). Kein Abgleich gegen `bluetooth_known_devices()` nötig -
schlägt die gespeicherte MAC fehl (Gerät zwischenzeitlich entfernt), läuft das
einfach in den ohnehin vorhandenen Fehlerpfad.

## State (`ui_state.py`)

Neue Felder auf `UIState`: `qc_active` (Overlay sichtbar), `qc_phase`
(`None`/`"hold"`/`"connecting"`/`"error"`), `qc_progress` (0.0-1.0),
`qc_error`. Neue Methoden `quick_connect_press()`, `quick_connect_release()`,
`quick_connect_tick()` (Fortschritt aus verstrichener Zeit berechnen, liefert
`True` genau einmal beim Überschreiten der Schwelle), `quick_connect_start()`
(prüft Vorbedingungen, liefert die MAC oder setzt selbst den Fehlerzustand),
`quick_connect_done(success, error)`, `quick_connect_error_tick()` (Auto-Dismiss
nach 1,5s). Gleiche Bauart wie `power_button.py`s Hold-Erkennung
(`_pressed_since`/Schwellenwert-Vergleich), nur als State-Methoden statt einer
eigenen Klasse, da es UI-State ist statt eines Hardware-Treibers.

## main.py

- `handle_event()`: `play_pause` `button_down` auf `SCREEN_HOME` startet den
  Hold (`quick_connect_press()`), `button_up` bricht ihn ab, falls noch in
  Phase `"hold"` (`quick_connect_release()`).
- Haupt-Loop: pro Iteration `quick_connect_tick()` aufrufen, solange
  `qc_phase == "hold"`; beim Schwellenübertritt `quick_connect_start()` holen
  und ggf. `bt_worker.start_quick_connect(mac)` anstoßen. Redraw während
  `"hold"`/`"connecting"` gedrosselt auf 0.1s (gleiches Intervall wie
  `PLAYING_REDRAW_INTERVAL`, deckt sowohl die Ring-Animation als auch das
  asynchrone `"connecting"→"error"`-Ende ab - der Erfolgsfall wird bereits vom
  bestehenden `state.screen != last_rendered_screen`-Check erfasst).
- `BTWorker.start_quick_connect(mac)` / `_quick_connect(mac)`: wie
  `start_device_action`, ruft aber `state.quick_connect_done(...)` statt
  `state.bt_device_action_done(...)` auf.

## Rendering (`ui_render.py`)

`render()` zeichnet nach dem eigentlichen Screen zusätzlich
`_draw_quick_connect(img, state)`, falls `state.qc_active` - Ring bei
`qc_progress < 1.0` als `draw.arc(...)`-Bogen, sonst als voller
`draw.ellipse(..., outline=...)`-Kreis; Text darüber (`TEXT`-Farbe normal,
Systemrot `(255, 69, 58)` im Fehlerfall).

## Testing

`test_ui_state.py`: Hold unter/über Schwelle, `quick_connect_start()` ohne
bekanntes Gerät bzw. ohne `last_played`, `quick_connect_done()` Erfolg
(→ `SCREEN_PLAYING`) und Fehler (→ `qc_phase == "error"`, Auto-Dismiss nach
Ablauf von `quick_connect_error_tick()`).

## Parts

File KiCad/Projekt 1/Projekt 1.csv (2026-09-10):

Reference | Qty | Value | DNP | Exclude from BOM | Exclude from Board | Exclude from Simulation | Exclude from Position Files | Footprint | Datasheet
4PinfuerBoard1,RundesDisplay1,Visualizer1 | 3 |  |  |  |  |  | ${EXCLUDE_FROM_POS_FILES} | EasyEDA_Lib:CONN-TH_B8B-PH-K-S-LF-SN | https://item.szlcsc.com/datasheet/B8B-PH-K-S(LF)(SN)/169322.html
AUDIO1 | 1 |  |  |  |  |  | ${EXCLUDE_FROM_POS_FILES} | EasyEDA_Lib:AUDIO-SMD_PJ-327C-4A | https://item.szlcsc.com/datasheet/PJ-327C-4A/157145.html
Battery1 | 1 |  |  |  |  |  | ${EXCLUDE_FROM_POS_FILES} | EasyEDA_Lib:CONN-TH_B2B-PH-K-S | https://item.szlcsc.com/datasheet/B2B-PH-K-S(LF)(SN)/142630.html
C1,C18,C20 | 3 | 2.2uF |  |  |  |  | ${EXCLUDE_FROM_POS_FILES} | EasyEDA_Lib:C0402 | https://item.szlcsc.com/datasheet/CGA0402X5R225M6R3GT/8593414.html
C2,C3,C7,C9,C11,C14,C16,C19,C23 | 9 | 100nF |  |  |  |  | ${EXCLUDE_FROM_POS_FILES} | EasyEDA_Lib:C0402 | https://item.szlcsc.com/datasheet/CC0402KRX5R9BB104/107097.html
C4,C5,C6 | 3 | 22uF |  |  |  |  | ${EXCLUDE_FROM_POS_FILES} | EasyEDA_Lib:C0402 | https://item.szlcsc.com/datasheet/GRM158C80G226ME01D/4423228.html
C8,C10 | 2 | 100uF |  |  |  |  | ${EXCLUDE_FROM_POS_FILES} | EasyEDA_Lib:C0805 | https://item.szlcsc.com/datasheet/GRM21BR60E107ME15L/538081.html
C12 | 1 | 1uF |  |  |  |  | ${EXCLUDE_FROM_POS_FILES} | EasyEDA_Lib:C0603 | https://item.szlcsc.com/datasheet/CL10B105KA8NNNC/30690.html
C13,C17,C25 | 3 | 10uF |  |  |  |  | ${EXCLUDE_FROM_POS_FILES} | EasyEDA_Lib:C0402 | https://item.szlcsc.com/datasheet/CGA0402X5R106M6R3GT/25421443.html
C15 | 1 | 47nF |  |  |  |  | ${EXCLUDE_FROM_POS_FILES} | EasyEDA_Lib:C0402 | https://item.szlcsc.com/datasheet/TCC0402X7R473K500AT/943136.html
C21,C24,C26 | 3 | 4.7uF |  |  |  |  | ${EXCLUDE_FROM_POS_FILES} | EasyEDA_Lib:C0402 | https://item.szlcsc.com/datasheet/CL05A475KP5NRNC/342854.html
CARD1 | 1 |  |  |  |  |  | ${EXCLUDE_FROM_POS_FILES} | EasyEDA_Lib:TF-SMD_TF-PUSH | https://item.szlcsc.com/datasheet/TF%2520PUSH/372553.html
D1 | 1 |  |  |  |  |  | ${EXCLUDE_FROM_POS_FILES} | EasyEDA_Lib:SOD-123F_L2.7-W1.6-LS3.8-RD | https://item.szlcsc.com/datasheet/1N4148W/82750.html
J1 | 1 | Boot Button |  |  |  |  | ${EXCLUDE_FROM_POS_FILES} | Connector_PinHeader_2.54mm:PinHeader_1x02_P2.54mm_Vertical
J2 | 1 | Switch |  |  |  |  | ${EXCLUDE_FROM_POS_FILES} | Connector_PinHeader_2.54mm:PinHeader_1x02_P2.54mm_Vertical
L1 | 1 | 1.5uH |  |  |  |  | ${EXCLUDE_FROM_POS_FILES} | EasyEDA_Lib:IND-SMD_L4.0-W4.0-A | https://www.coilcraft.com/getmedia/50632d43-da1b-4cdb-8ab4-3029cab51df3/xfl4020.pdf
L2 | 1 | 1uH |  |  |  |  | ${EXCLUDE_FROM_POS_FILES} | EasyEDA_Lib:L2520 | https://item.szlcsc.com/datasheet/DFE252012F-1R0M%253DP2/432730.html
LED1,LED2,LED3,LED4,LED5,LED6 | 6 |  |  |  |  |  | ${EXCLUDE_FROM_POS_FILES} | EasyEDA_Lib:LED-SMD_4P-L3.2-W2.8-LS5.9_SK6812MINI-E | https://item.szlcsc.com/datasheet/SK6812MINI-E/5773397.html
Module1 | 1 | ComputeModule4-CM4 |  |  |  |  | ${EXCLUDE_FROM_POS_FILES} | Pertificatus:CONN-SMD_DF40HC-3.0-100DS-0.4V-51
Q1 | 1 |  |  |  |  |  | ${EXCLUDE_FROM_POS_FILES} | EasyEDA_Lib:SOT-23_L2.9-W1.3-P1.90-LS2.4-BR | https://item.szlcsc.com/datasheet/AO3401A/15801.html
R1,R10,R11 | 3 | 5.1kΩ |  |  |  |  | ${EXCLUDE_FROM_POS_FILES} | EasyEDA_Lib:R0603
R2,R5 | 2 | 33Ω |  |  |  |  | ${EXCLUDE_FROM_POS_FILES} | EasyEDA_Lib:R0603 | https://item.szlcsc.com/datasheet/FRC0603F33R0TS/3186329.html
R3 | 1 | 180kΩ |  |  |  |  | ${EXCLUDE_FROM_POS_FILES} | EasyEDA_Lib:R0603
R4 | 1 | 1.6MΩ |  |  |  |  | ${EXCLUDE_FROM_POS_FILES} | EasyEDA_Lib:R0603 | https://item.szlcsc.com/datasheet/FRC0603J165%2520TS/3279374.html
R6,R7 | 2 | 0Ω |  |  |  |  | ${EXCLUDE_FROM_POS_FILES} | EasyEDA_Lib:R0603 | https://item.szlcsc.com/datasheet/RC0603JR-070RL/96378.html
R8 | 1 | 10Ω |  |  |  |  | ${EXCLUDE_FROM_POS_FILES} | EasyEDA_Lib:R0603 | https://item.szlcsc.com/datasheet/CRCW060310R0FKEA/904493.html
R9 | 1 | 178Ω |  |  |  |  | ${EXCLUDE_FROM_POS_FILES} | EasyEDA_Lib:R0603 | https://item.szlcsc.com/datasheet/1RC0603F1780/57883862.html
R12 | 1 | 220Ω |  |  |  |  | ${EXCLUDE_FROM_POS_FILES} | EasyEDA_Lib:R0603 | https://atta.szlcsc.com/upload/public/pdf/source/20200306/C422600_1E6D84923E4A46A82E41ADD87F860B5C.pdf
R13,R14 | 2 | 100kΩ |  |  |  |  | ${EXCLUDE_FROM_POS_FILES} | EasyEDA_Lib:R0603 | https://item.szlcsc.com/datasheet/RC0603FR-07100KL/15343.html
R15,R16 | 2 | 50kΩ |  |  |  |  | ${EXCLUDE_FROM_POS_FILES} | EasyEDA_Lib:R0603 | https://item.szlcsc.com/datasheet/RT0603BRD0750KL/921789.html
U1 | 1 |  |  |  |  |  | ${EXCLUDE_FROM_POS_FILES} | EasyEDA_Lib:TDFN-8_L2.0-W2.0-P0.50-BL-EP1.2 | https://item.szlcsc.com/datasheet/MAX17048G%252BT10/2777647.html
U2 | 1 |  |  |  |  |  | ${EXCLUDE_FROM_POS_FILES} | EasyEDA_Lib:QFN-28_L4.0-W4.0-P0.45-BL-EP | https://item.szlcsc.com/datasheet/ES8388/339918.html
U3 | 1 |  |  |  |  |  | ${EXCLUDE_FROM_POS_FILES} | EasyEDA_Lib:VSON-14_L4.0-W3.0-P0.50-BL-EP_TI_DSJ | https://www.ti.com/cn/lit/gpn/tps63020
U4 | 1 |  |  |  |  |  | ${EXCLUDE_FROM_POS_FILES} | EasyEDA_Lib:WQFN-24_L4.0-W4.0-P0.50-TL-EP2.5 | https://item.szlcsc.com/datasheet/RT9466GQW/3578183.html
U5 | 1 |  |  |  |  |  | ${EXCLUDE_FROM_POS_FILES} | EasyEDA_Lib:LGA-14_L3.0-W2.5-P0.50-TL | https://item.szlcsc.com/datasheet/QMI8658A/3544058.html
U6 | 1 |  |  |  |  |  | ${EXCLUDE_FROM_POS_FILES} | EasyEDA_Lib:SOT-23-5_L3.0-W1.7-P0.95-LS2.8-BR | https://www.ti.com/cn/lit/ds/symlink/sn74ahct1g125.pdf
USBC1 | 1 |  |  |  |  |  | ${EXCLUDE_FROM_POS_FILES} | EasyEDA_Lib:USB-C_SMD-TYPE-C-31-M-12_1 | https://item.szlcsc.com/datasheet/TYPE-C-31-M-12/177331.html

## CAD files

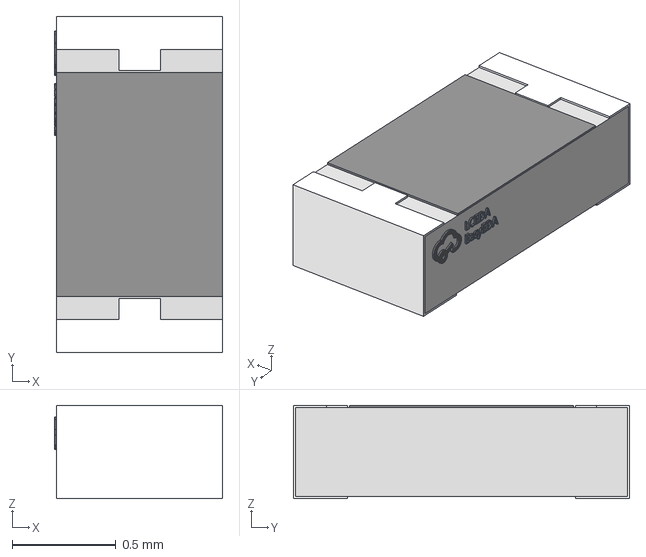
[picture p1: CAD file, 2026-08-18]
KiCad/Projekt 1/ButtonBox/EASYEDA_MODELS/R0603.step
0.81 x 1.62 x 0.45 mm

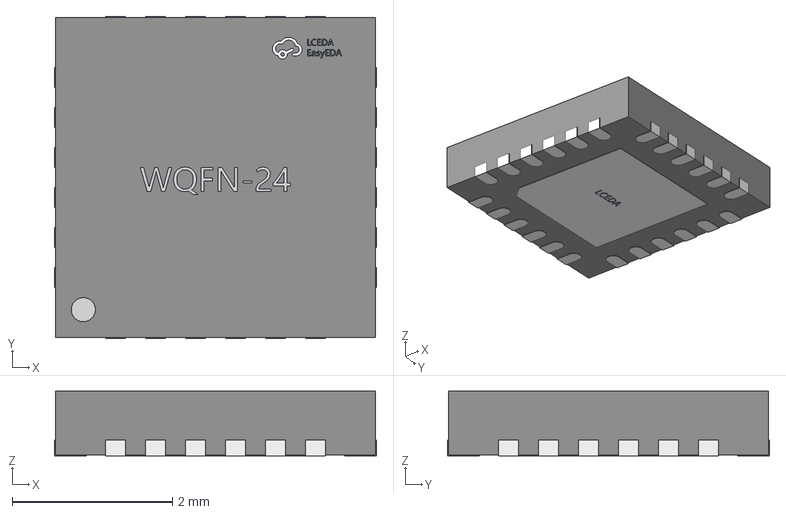
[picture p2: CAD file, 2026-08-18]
KiCad/Projekt 1/EASYEDA_MODELS/WQFN-24_L4.0-W4.0-H0.8-P0.50.step
4.02 x 4.02 x 0.811 mm

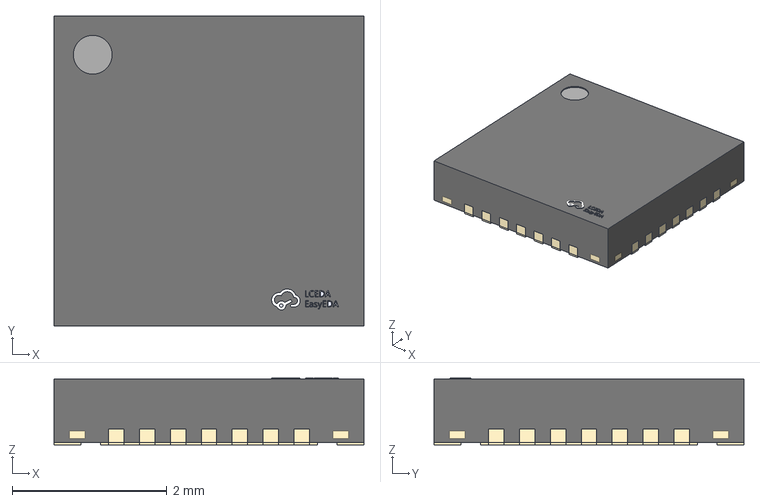
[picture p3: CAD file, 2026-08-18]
KiCad/Projekt 1/ButtonBox/EASYEDA_MODELS/QFN-28_L4.0-W4.0-H0.9-P0.40-BL-EP.step
4.00 x 4.00 x 0.86 mm

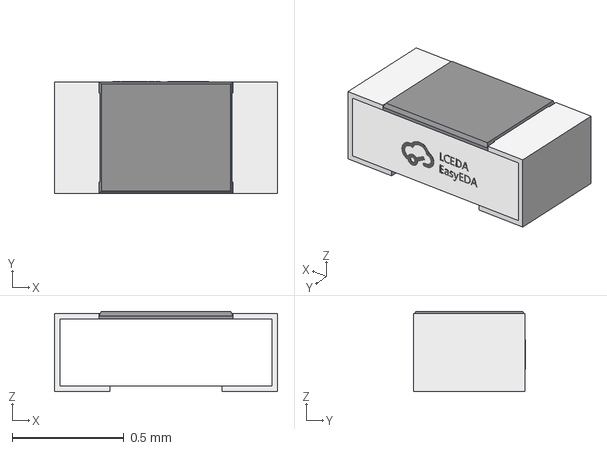
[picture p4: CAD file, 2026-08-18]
KiCad/Projekt 1/EASYEDA_MODELS/R0402_L1.0-W0.5-H0.4.step
1.00 x 0.501 x 0.36 mm

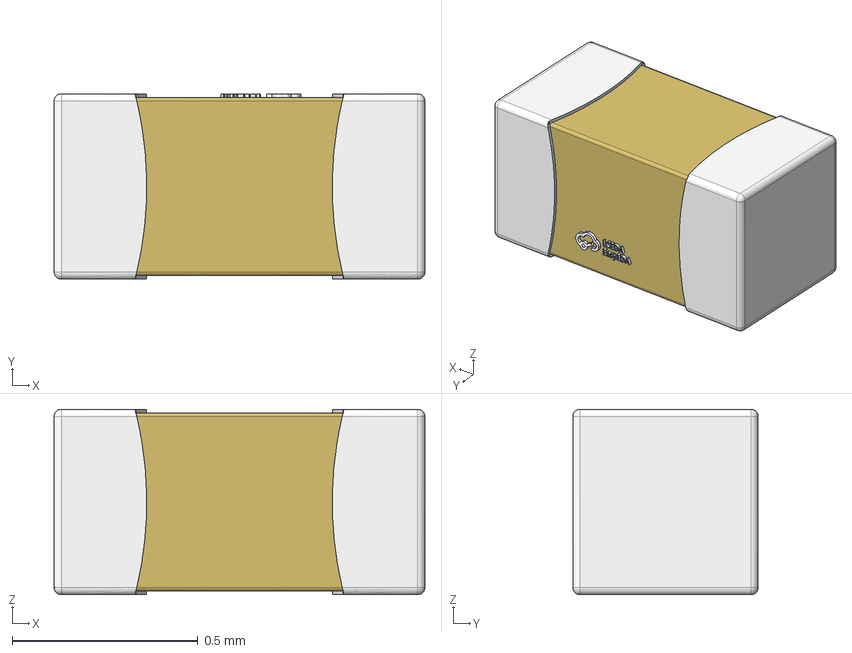
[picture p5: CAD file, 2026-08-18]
KiCad/Projekt 1/ButtonBox/EASYEDA_MODELS/C0402_L1.0-W0.5-H0.5.step
1.00 x 0.5 x 0.5 mm

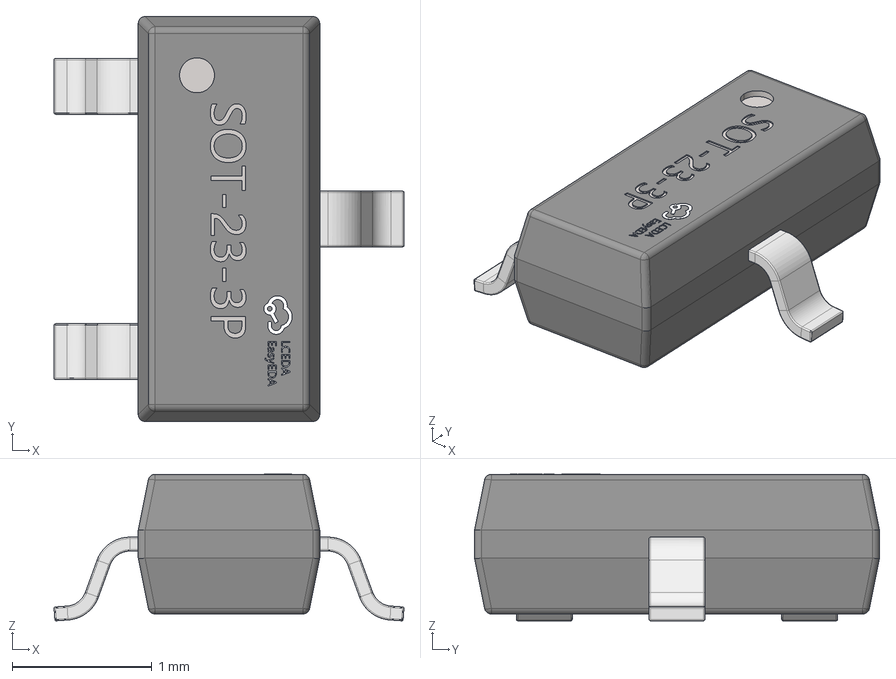
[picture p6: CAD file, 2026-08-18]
KiCad/Projekt 1/EASYEDA_MODELS/SOT-23-3P_L2.9-W1.3-H1.0-LS2.4-P0.95.step
2.51 x 2.90 x 1.05 mm

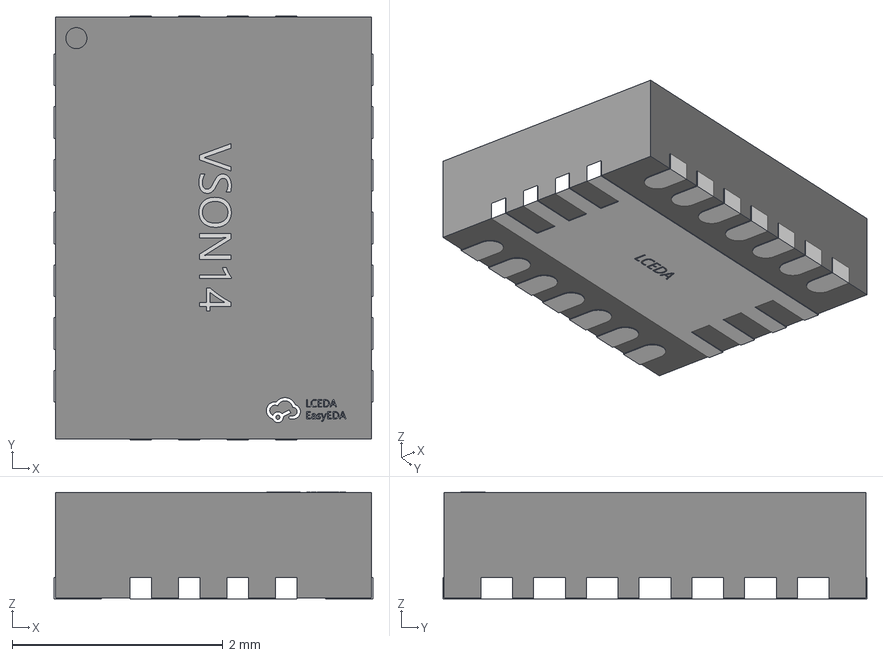
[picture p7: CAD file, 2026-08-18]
KiCad/Projekt 1/EASYEDA_MODELS/VSON-14_L4.0-W3.0-H1.0-P0.50.step
3.02 x 4.02 x 1.01 mm

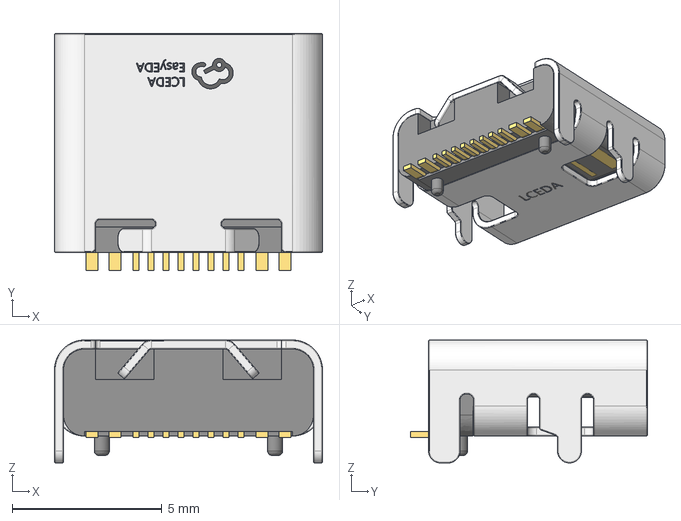
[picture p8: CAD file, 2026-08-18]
KiCad/Projekt 1/EASYEDA_MODELS/USB-C_SMD-TYPE-C-31-M-12_1.step
8.94 x 7.90 x 4.10 mm

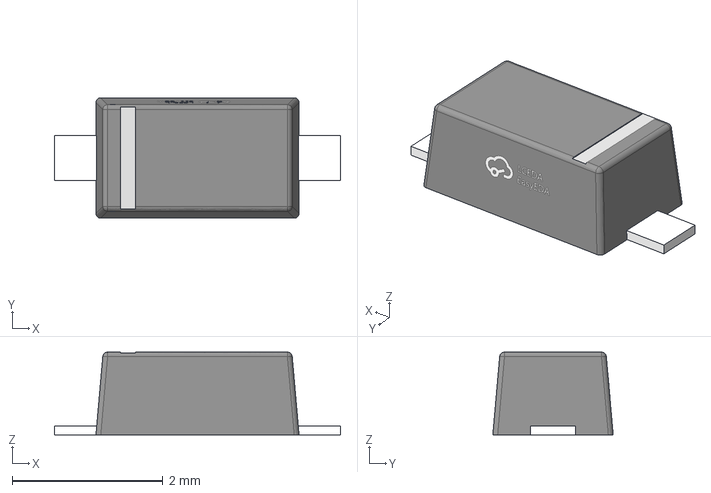
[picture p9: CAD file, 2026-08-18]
KiCad/Projekt 1/EASYEDA_MODELS/SOD-123F_L2.7-W1.6-LS3.8-RD.step
3.80 x 1.60 x 1.10 mm

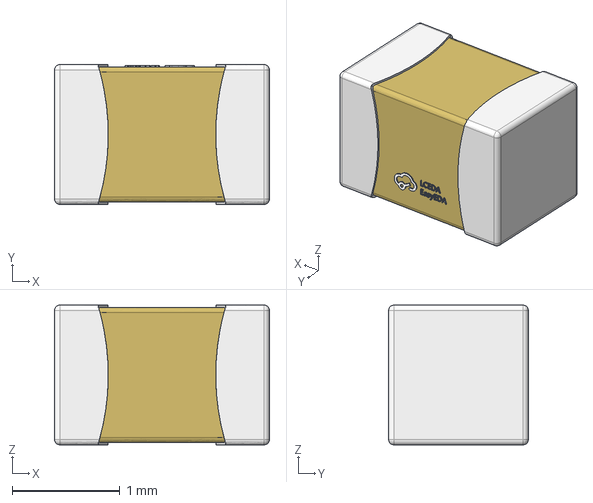
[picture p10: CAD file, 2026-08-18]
KiCad/Projekt 1/EASYEDA_MODELS/C0805_L2.0-W1.3-H1.3.step
2.00 x 1.30 x 1.30 mm

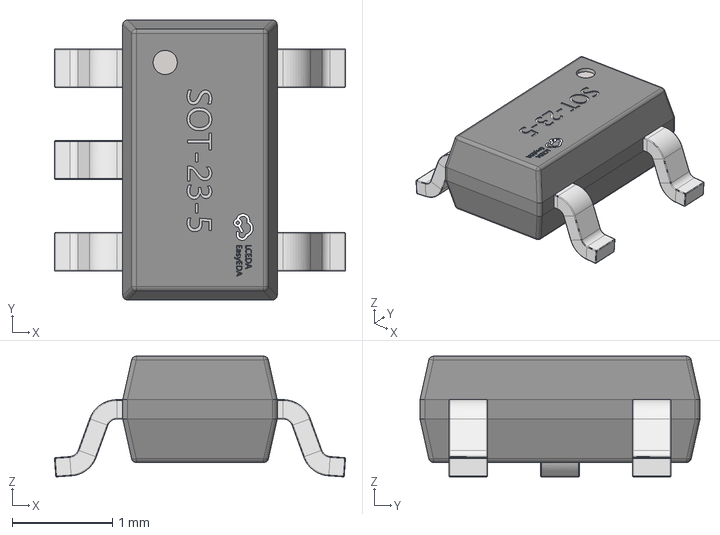
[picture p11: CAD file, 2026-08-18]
KiCad/Projekt 1/EASYEDA_MODELS/SOT-23-5_L2.9-W1.6-H1.1-LS2.8-P0.95.step
2.90 x 2.79 x 1.20 mm

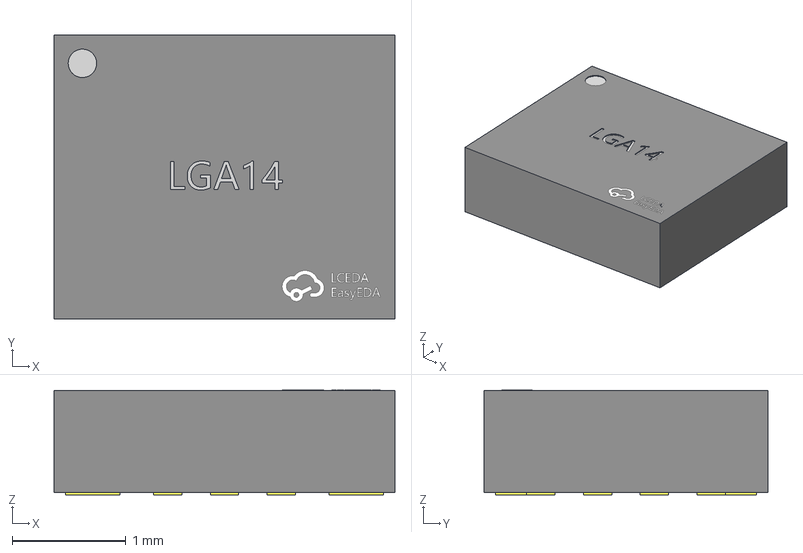
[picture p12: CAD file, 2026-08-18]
KiCad/Projekt 1/EASYEDA_MODELS/LGA-14_L2.5-W3.0-H0.9-P0.50.step
3.00 x 2.50 x 0.921 mm

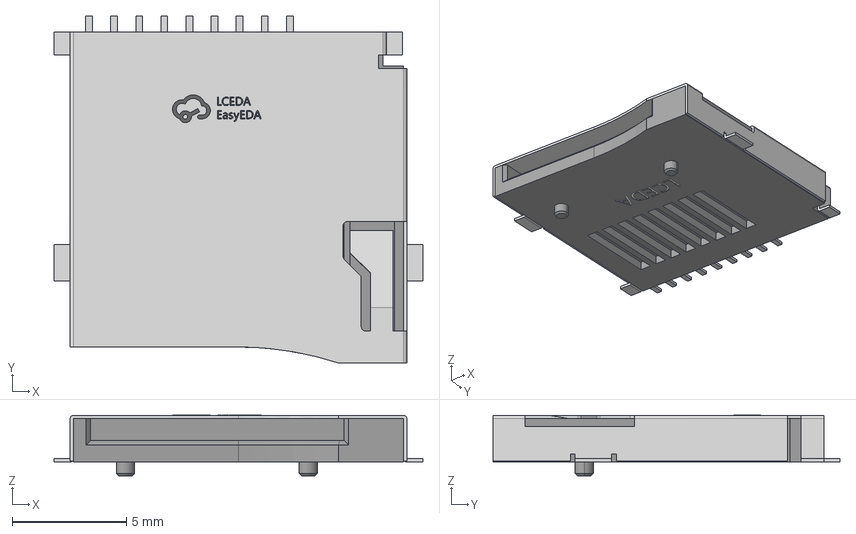
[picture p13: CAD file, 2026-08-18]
KiCad/Projekt 1/EASYEDA_MODELS/TF-SMD_TF-PUSH.step
16.1 x 15.2 x 2.65 mm

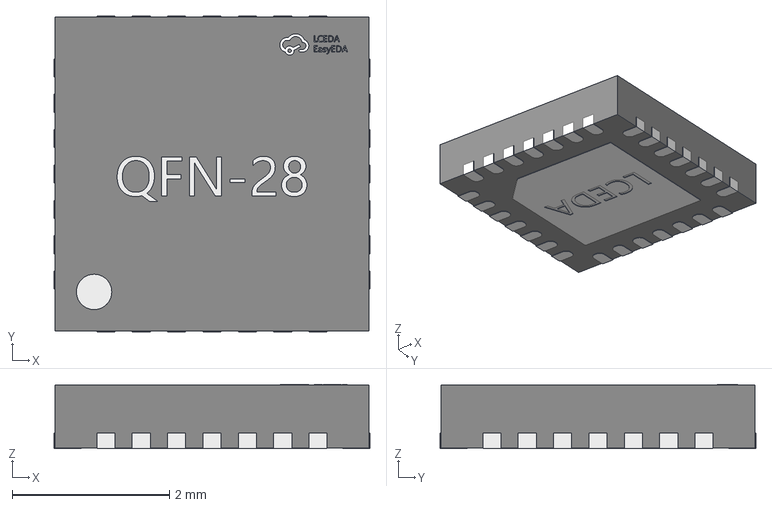
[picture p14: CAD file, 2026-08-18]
KiCad/Projekt 1/EASYEDA_MODELS/QFN-28_L4.0-W4.0-H0.8-P0.45.step
4.02 x 4.02 x 0.82 mm

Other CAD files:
KiCad/Projekt 1/EASYEDA_MODELS/R0603.step
KiCad/Projekt 1/EASYEDA_MODELS/QFN-28_L4.0-W4.0-H0.9-P0.40-BL-EP.step
KiCad/Projekt 1/EASYEDA_MODELS/C0603_L1.6-W0.8-H0.8.step
KiCad/Projekt 1/EASYEDA_MODELS/CONN-TH_PH2.00-LI-8P.step
KiCad/Projekt 1/EASYEDA_MODELS/AUDIO-SMD_L11.8-W6.0-H5.0-4P.step
KiCad/Projekt 1/EASYEDA_MODELS/C0402_L1.0-W0.5-H0.5.step
KiCad/Projekt 1/EASYEDA_MODELS/CONN-TH_PH2.00-LI-2P.step
KiCad/Projekt 1/EASYEDA_MODELS/L2520.step
KiCad/Projekt 1/EASYEDA_MODELS/TDFN-8_L2.0-W2.0-P0.50-BL-EP1.2.step

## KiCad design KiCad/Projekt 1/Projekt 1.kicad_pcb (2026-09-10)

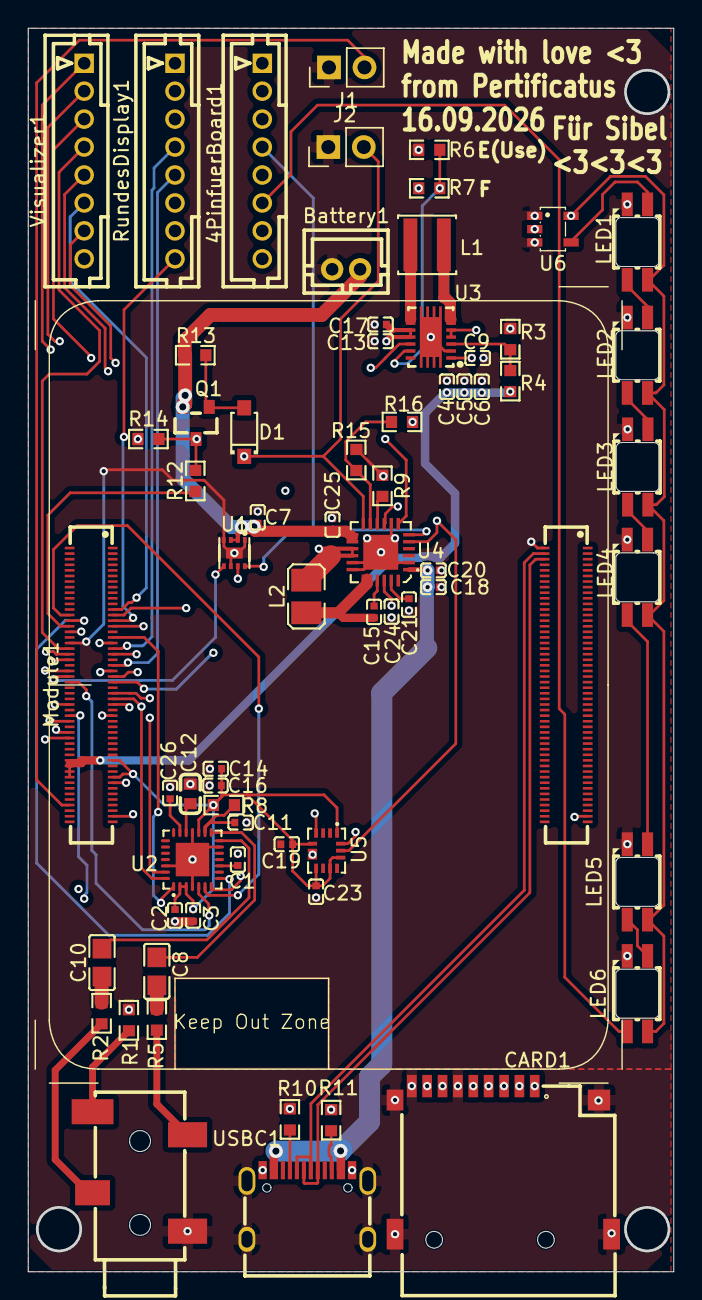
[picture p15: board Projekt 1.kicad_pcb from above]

Board: 4 copper layers, 46.2 x 89.0 mm, 67 parts (0 on the bottom side), 74 nets.

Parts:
4PinfuerBoard1: CONN-TH_B8B-PH-K-S-LF-SN
AUDIO1: AUDIO-SMD_PJ-327C-4A
Battery1: CONN-TH_B2B-PH-K-S
C1, C18, C20: 2.2uF; C0402
C2, C3, C7, C9, C11, C14, C16, C19, C23: 100nF; C0402
C4, C5, C6: 22uF; C0402
C8, C10: 100uF; C0805
C12: 1uF; C0603
C13, C17, C25: 10uF; C0402
C15: 47nF; C0402
C21, C24, C26: 4.7uF; C0402
CARD1: TF-SMD_TF-PUSH
D1: SOD-123F_L2.7-W1.6-LS3.8-RD
J1: Boot Button; PinHeader_1x02_P2.54mm_Vertical
J2: Switch; PinHeader_1x02_P2.54mm_Vertical
L1: 1.5uH; IND-SMD_L4.0-W4.0-A
L2: 1uH; L2520
LED1, LED2, LED3, LED4, LED5, LED6: LED-SMD_4P-L3.2-W2.8-LS5.9_SK6812MINI-E
Module1: ComputeModule4-CM4; CONN-SMD_DF40HC-3.0-100DS-0.4V-51
Q1: SOT-23_L2.9-W1.3-P1.90-LS2.4-BR
R1, R10, R11: 5.1kΩ; R0603
R2, R5: 33Ω; R0603
R3: 180kΩ; R0603
R4: 1.6MΩ; R0603
R6, R7: 0Ω; R0603
R8: 10Ω; R0603
R9: 178Ω; R0603
R12: 220Ω; R0603
R13, R14: 100kΩ; R0603
R15, R16: 50kΩ; R0603
RundesDisplay1: CONN-TH_B8B-PH-K-S-LF-SN
U1: TDFN-8_L2.0-W2.0-P0.50-BL-EP1.2
U2: QFN-28_L4.0-W4.0-P0.45-BL-EP
U3: VSON-14_L4.0-W3.0-P0.50-BL-EP_TI_DSJ
U4: WQFN-24_L4.0-W4.0-P0.50-TL-EP2.5
U5: LGA-14_L3.0-W2.5-P0.50-TL
U6: SOT-23-5_L3.0-W1.7-P0.95-LS2.8-BR
USBC1: USB-C_SMD-TYPE-C-31-M-12_1
Visualizer1: CONN-TH_B8B-PH-K-S-LF-SN

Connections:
GND: AUDIO1.1, Battery1.2, C1.2, C2.1, C3.1, C4.2, C5.2, C6.2, C7.1, C9.1, C11.2, C12.2, C13.1, C14.2, C16.1, C17.1, C18.1, C19.1, C20.1, C21.2, C23.1, C24.1, C25.1, C26.1, CARD1.6 (VSS), CARD1.10, CARD1.11, CARD1.12, CARD1.13, CARD1.CD, J1.1, J2.1, LED1.1 (GND), LED2.1 (GND), LED3.1 (GND), LED4.1 (GND), LED5.1 (GND), LED6.1 (GND), Module1.35 (ID_SC), Module1.101 (USB_OTG_ID), Module1.198 (GND), R1.2, R3.2, R6.1, R9.1, R10.1, R11.1, R14.1, R15.2, U1.1 (CTG), U1.4 (GND), U1.6 (QSTRT), U1.9 (EP), U2.4 (DGND), U2.13 (HPGND), U2.18 (AGND), U2.26 (CE), U2.29 (EP), U3.2 (GND), U3.15 (PGND), U4.2 (PSEL), U4.8 (OTG), U4.17 (PGND), U4.18 (PGND), U4.25 (EP), U5.6 (GND), U5.7 (GND), U6.1 (OE#), U6.3 (GND), USBC1.1 (EH), USBC1.2 (EH), USBC1.3 (EH), USBC1.4 (EH), USBC1.A1B12 (GND), USBC1.B1A12 (GND)
unnamed: 4PinfuerBoard1.3, Module1.98 (GND), RundesDisplay1.3, Visualizer1.3
unnamed: AUDIO1.2, R5.1
unnamed: AUDIO1.3, R2.1
unnamed: AUDIO1.4, R1.1
unnamed: C8.1, R5.2
unnamed: C10.1, R2.2
unnamed: C15.2, L2.1, U4.19 (LX), U4.20 (LX)
unnamed: CARD1.2 (CD/DAT3), Module1.61 (SD_DAT3)
unnamed: CARD1.5 (CLX), Module1.57 (SD_CLK)
unnamed: CARD1.3 (CMD), Module1.62 (SD_CMD)
unnamed: CARD1.7 (DAT0), Module1.63 (SD_DAT0)
unnamed: CARD1.8 (DAT1), Module1.67 (SD_DAT1)
unnamed: CARD1.1 (DAT2), Module1.69 (SD_DAT2)
unnamed: 4PinfuerBoard1.1, CARD1.4 (VDD), Module1.86 (+3.3v_(Output)), RundesDisplay1.1, Visualizer1.1
unnamed: D1.2 (A), Q1.1 (G), R13.1
unnamed: D1.1 (K), J2.2, Module1.40 (GPIO9), U4.12 (#QON)
unnamed: J1.2, Module1.93 (nRPIBOOT)
unnamed: L1.1, U3.6 (L2), U3.7 (L2)
unnamed: L1.2, U3.8 (L1), U3.9 (L1)
unnamed: LED1.2 (DIN), U6.4 (Y)
unnamed: LED1.4 (DOUT), LED2.2 (DIN)
unnamed: 4PinfuerBoard1.5, C4.1, C5.1, C6.1, LED1.3 (VDD), LED2.3 (VDD), LED3.3 (VDD), LED4.3 (VDD), LED5.3 (VDD), LED6.3 (VDD), Module1.77 (+5v_(Input)), Module1.79 (+5v_(Input)), Module1.81 (+5v_(Input)), Module1.83 (+5v_(Input)), R4.2, U3.4 (VOUT), U3.5 (VOUT), U6.5 (VCC)
unnamed: LED2.4 (DOUT), LED3.2 (DIN)
unnamed: LED3.4 (DOUT), LED4.2 (DIN)
unnamed: LED4.4 (DOUT), LED5.2 (DIN)
unnamed: LED5.4 (DOUT), LED6.2 (DIN)
unnamed: 4PinfuerBoard1.6, LED6.4 (DOUT)
unnamed: 4PinfuerBoard1.4, Module1.58 (GPIO2), U1.8 (SDA), U2.27 (CDATA), U4.6 (SDA), U5.14 (SDA)
unnamed: 4PinfuerBoard1.2, Module1.56 (GPIO3), U1.7 (SCL), U2.28 (CCLK), U4.5 (SCL), U5.13 (SCL)
unnamed: Module1.54 (GPIO4), Visualizer1.7
unnamed: Module1.34 (GPIO5), U2.1 (MCLK)
unnamed: Module1.30 (GPIO6), Visualizer1.5
unnamed: Module1.37 (GPIO7), Visualizer1.4
unnamed: Module1.39 (GPIO8), RundesDisplay1.7
unnamed: Module1.44 (GPIO10), RundesDisplay1.5
unnamed: Module1.38 (GPIO11), RundesDisplay1.4
unnamed: Module1.31 (GPIO12), U6.2 (A)
unnamed: Module1.28 (GPIO13), RundesDisplay1.8
unnamed: Module1.29 (GPIO16), R12.1
unnamed: Module1.50 (GPIO17), U4.9 (CEB)
unnamed: Module1.49 (GPIO18), U2.5 (SCLK)
unnamed: Module1.26 (GPIO19), U2.7 (LRCK)
unnamed: Module1.27 (GPIO20), U2.8 (ASDOUT)
unnamed: Module1.25 (GPIO21), U2.6 (DSDIN)
unnamed: Module1.46 (GPIO22), U4.7 (INT)
unnamed: Module1.47 (GPIO23), U1.5 (ALRT#)
unnamed: Module1.45 (GPIO24), RundesDisplay1.6
unnamed: Module1.41 (GPIO25), RundesDisplay1.2
unnamed: Module1.24 (GPIO26), Visualizer1.6
unnamed: Module1.48 (GPIO27), Visualizer1.2
unnamed: C2.2, C3.2, C14.1, C16.2, C19.2, C23.2, Module1.78 (GPIO_VREF(1.8v/3.3v_Input)), Module1.84 (+3.3v_(Output)), R8.2, U2.2 (DVDD), U2.3 (PVDD), U2.17 (AVDD), U5.1 (SDO/SA0), U5.5 (VDDIO), U5.8 (VDD), U5.10 (CS-AUX), U5.12 (CS)
unnamed: Module1.36 (ID_SD), U5.4 (INT1)
unnamed: Module1.103 (USB2_N), USBC1.A7 (DN1), USBC1.B7 (DN2)
unnamed: Module1.105 (USB2_P), USBC1.A6 (DP1), USBC1.B6 (DP2)
unnamed: Q1.3 (D), R12.2, R14.2, U3.12 (EN)
unnamed: Battery1.1, C7.2, C25.2, Q1.2 (S), R13.2, U1.2 (CELL), U1.3 (VDD), U4.13 (BAT), U4.14 (BAT)
unnamed: C12.1, U2.19 (ADCVREF)
unnamed: C11.1, R8.1, U2.16 (HPVDD)
unnamed: C8.2, U2.15 (LOUT2)
unnamed: C10.2, U2.14 (ROUT2)
unnamed: C26.2, U2.20 (VMID)
unnamed: C1.1, U2.10 (VREF)
unnamed: R3.1, R4.1, U3.3 (FB)
unnamed: R6.2, R7.2, U3.13 (PS/SYNC)
unnamed: C9.2, C13.2, C17.2, L2.2, R7.1, U3.1 (VINA), U3.10 (VIN), U3.11 (VIN), U4.15 (SYS), U4.16 (SYS)
unnamed: C15.1, U4.21 (BTST)
unnamed: R9.2, U4.10 (ILIM)
unnamed: C24.2, R16.1, U4.22 (REGN)
unnamed: R15.1, R16.2, U4.11 (TS)
unnamed: C18.2, C20.2, U4.1 (VBUS), USBC1.A4B9 (VBUS), USBC1.B4A9 (VBUS)
unnamed: C21.1, U4.23 (VMID)
unnamed: R10.2, USBC1.A5 (CC1)
unnamed: R11.2, USBC1.B5 (CC2)

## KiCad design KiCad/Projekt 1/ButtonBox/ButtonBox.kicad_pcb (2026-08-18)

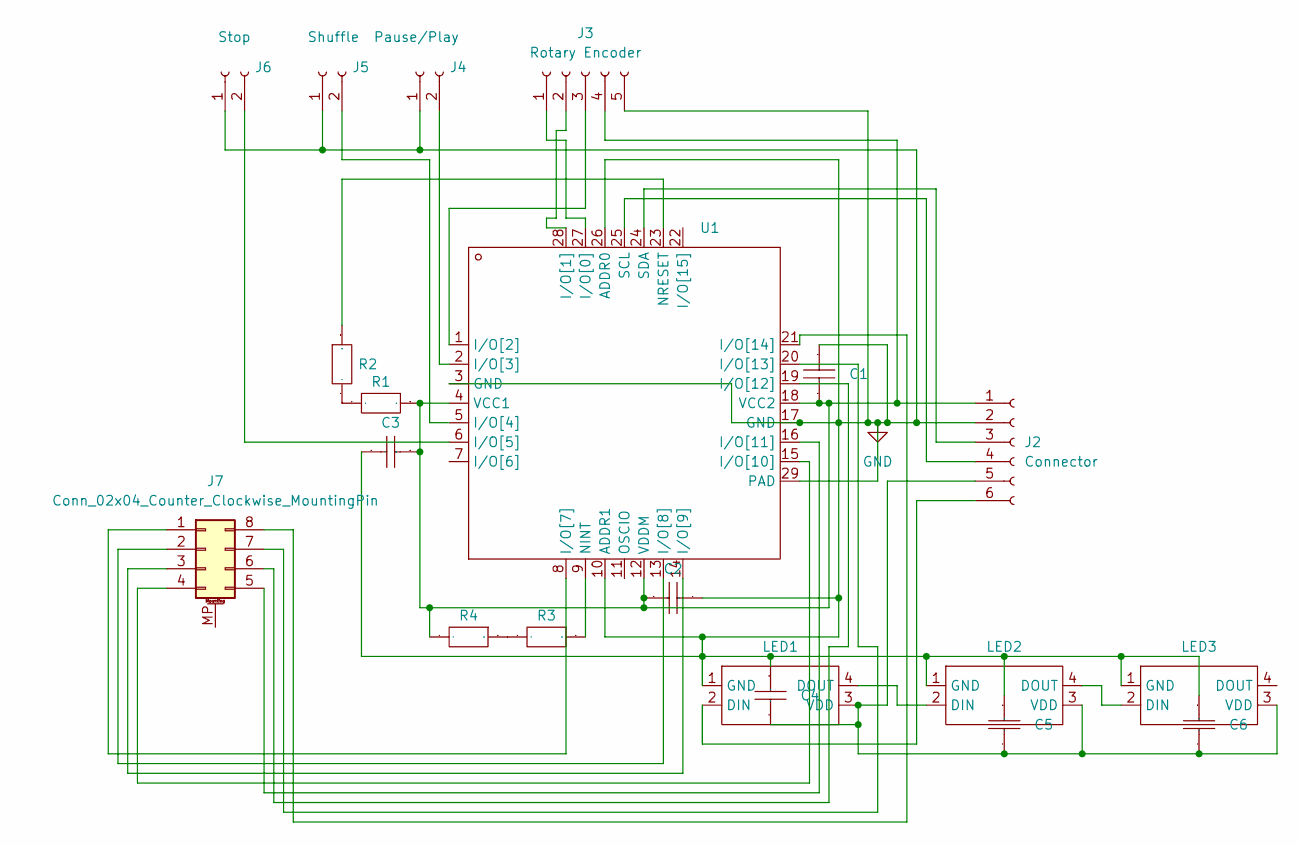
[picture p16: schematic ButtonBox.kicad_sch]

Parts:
C1, C2, C3, C4, C5, C6: 100nF; C0402; Manufacturer Part CC0402KRX5R9BB104; LCSC Part Name 100nF ±10% 50V
J2: Connector; 6Pin
J3: Rotary Encoder; 5PinRotary
J4: Pause/Play; 2PinKlick
J5: Shuffle; 2PinKlick
J6: Stop; 2PinKlick
J7: Conn_02x04_Counter_Clockwise_MountingPin; 8Pin
LED1, LED2, LED3: LED-SMD_4P-L3.2-W2.8-LS5.9_SK6812MINI-E; Manufacturer Part SK6812MINI-E; LCSC Part Name 工作电压5V、发光角度120°、灰度调节256级的RGB LED
R1, R2, R3, R4: 5.1kΩ; R0603; Manufacturer Part FRC0603F5101TS; LCSC Part Name 5.1kΩ ±1% 100mW 厚膜电阻
U1: QFN-28_L4.0-W4.0-P0.40-BL-EP; Manufacturer Part SX1509BIULTRT; LCSC Part Name SX1509BIULTRT

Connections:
GND: C1.2, C2.1, C3.2, C4.1, C5.1, C6.1, J2.2, J3.5, J4.1, J5.1, J6.1, LED1.1 (GND), LED2.1 (GND), LED3.1 (GND), U1.3 (GND), U1.10 (ADDR1), U1.17 (GND), U1.26 (ADDR0), U1.29 (PAD)
unnamed: C1.1, C2.2, C3.1, J2.1, J3.4, R1.1, R4.2, U1.4 (VCC1), U1.12 (VDDM), U1.18 (VCC2)
unnamed: J2.3, U1.24 (SDA)
unnamed: J2.4, U1.25 (SCL)
unnamed: C4.2, C5.2, C6.2, J2.5, LED1.3 (VDD), LED2.3 (VDD), LED3.3 (VDD)
unnamed: J2.6, LED1.2 (DIN)
unnamed: J3.1, U1.27 (I/O[0])
unnamed: J3.2, U1.28 (I/O[1])
unnamed: J3.3, U1.1 (I/O[2])
unnamed: J4.2, U1.2 (I/O[3])
unnamed: J5.2, U1.5 (I/O[4])
unnamed: J6.2, U1.6 (I/O[5])
unnamed: J7.1, U1.8 (I/O[7])
unnamed: J7.2, U1.13 (I/O[8])
unnamed: J7.3, U1.14 (I/O[9])
unnamed: J7.4, U1.15 (I/O[10])
unnamed: J7.5, U1.16 (I/O[11])
unnamed: J7.6, U1.19 (I/O[12])
unnamed: J7.7, U1.20 (I/O[13])
unnamed: J7.8, U1.21 (I/O[14])
unnamed: LED1.4 (DOUT), LED2.2 (DIN)
unnamed: LED2.4 (DOUT), LED3.2 (DIN)
unnamed: R1.2, R2.2
unnamed: R3.2, R4.1
unnamed: R3.1, U1.9 (NINT)
unnamed: R2.1, U1.23 (NRESET)

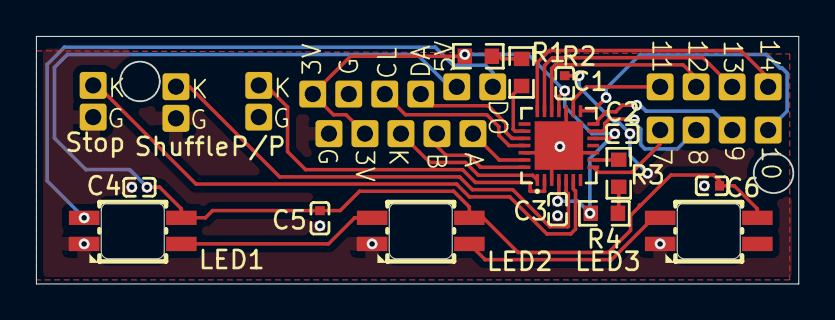
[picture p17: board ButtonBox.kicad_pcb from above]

Board: 2 copper layers, 42.3 x 13.8 mm, 20 parts (0 on the bottom side), 26 nets.

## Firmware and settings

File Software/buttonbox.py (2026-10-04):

"""ButtonBox input driver (SX1509 I2C GPIO expander).

Hardware wiring, see KiCad/Projekt 1/ButtonBox/ButtonBox.net:
  I/O0 = rotary encoder A
  I/O1 = rotary encoder B
PIN_ENC_A/PIN_ENC_B below are swapped relative to that netlist labeling - rotation
direction came out reversed on real hardware (turning CW registered as CCW), and
swapping which pin feeds which bit of the Gray-code reading is the correct fix
for that (rather than negating `direction` after the fact, which would be
correct for rotate events but silently leave any future A/B-relative decode
logic - e.g. distinguishing a stuck line - reasoning about the wrong pin).
  I/O2 = rotary encoder switch (click)
  I/O3 = Play/Pause button
  I/O4 = Shuffle button
  I/O5 = Stop button
All active-low (pulled to GND when pressed/rotated), SX1509 internal pull-ups used.
NINT is not wired to the Pi -> must be polled, no interrupt-driven reads.
"""
import queue
import threading
import time
from smbus2 import SMBus

SX1509_ADDR = 0x3E  # ADDR0/ADDR1 both tied to GND; confirm with i2cdetect after soldering
BUS = 1

REG_DIR_A = 0x0F
REG_PULLUP_A = 0x07
REG_DATA_A = 0x11

PIN_ENC_A = 1
PIN_ENC_B = 0
PIN_ENC_SW = 2
PIN_PLAY_PAUSE = 3
PIN_SHUFFLE = 4
PIN_STOP = 5

BUTTON_NAMES = {
    PIN_PLAY_PAUSE: "play_pause",
    PIN_SHUFFLE: "shuffle",
    PIN_STOP: "stop",
    PIN_ENC_SW: "knob",
}

# Quadrature decode, ported from the proven approach in a sister project
# (../CubeLED/Arduino/V8/V8.ino handleEncoder()/handleEncoderISR()): keep a
# LIFETIME running tally of net quarter-steps that never resets, and only
# report a click when floor-toward-zero(tally / DETENT_STEPS) actually
# changes from the last report.
#
# Two earlier attempts both failed on real hardware (see NOTES_FOR_PER.md):
# DETENT_STEPS=4 with an accumulator that RESET to 0 every time a reversal
# came in lost real rotation to what turned out to be the encoder settling
# back and forth around its own rest position (not bounce - a real hardware
# log showed it flipping cleanly between two adjacent Gray states, e.g.
# 11<->01, repeatedly, seemingly on its own). DETENT_STEPS=1 then fired on
# every one of those flips, i.e. on the noise itself - matching "jumps
# back immediately" almost every time. A never-reset running tally fixes
# both: a 11<->01<->11<->01 wobble keeps the tally oscillating between two
# adjacent small integers forever without ever crossing a DETENT_STEPS
# boundary, so it's silently absorbed - while genuine sustained rotation in
# one direction keeps pushing the tally further and eventually crosses one.
#
# DETENT_STEPS=4 (a full clean Gray cycle per click, matching CubeLED) had
# been lowered to 2 because the encoder never seemed to complete a clean
# 4-step cycle - but that turned out to be the ENC_DEBOUNCE_S/poll-rate bug
# described above (2-3ms-lived intermediate states were getting silently
# dropped), not the encoder. A raw, undebounced 2ms-poll capture on real
# hardware (12.09.2026, see NOTES_FOR_PER.md) proved the mechanism itself
# completes the full 4-step cycle cleanly on every single click with zero
# bounce. With that fixed, DETENT_STEPS=2 instead causes new symptoms of its
# own: a full click now reliably crosses the boundary TWICE (double steps),
# and a click that overshoots the detent by one quarter-step and springs
# back can straddle the 2-boundary and immediately un-cross it (fires
# forward then immediately back). Back to 4: one full clean cycle now maps
# to exactly one report, and a minor overshoot can't come close to
# reversing a full 4 ticks, so it's absorbed by the tally with no extra
# time-based filtering needed.
_GRAY_CYCLE = (0b00, 0b01, 0b11, 0b10)  # index i -> i+1 (mod 4) is one CW quarter-step
_GRAY_INDEX = {reading: i for i, reading in enumerate(_GRAY_CYCLE)}
DETENT_STEPS = 4


def decode_encoder_step(state, curr_reading):
    """One decode step. `state` is (raw_ticks, prev_reading, last_reported) -
    start with (0, <any valid reading>, 0). raw_ticks never resets. Returns
    (new_state, direction) where direction is +1 / -1 / None."""
    raw_ticks, prev_reading, last_reported = state
    if curr_reading not in _GRAY_INDEX or prev_reading not in _GRAY_INDEX:
        return (raw_ticks, curr_reading, last_reported), None

    delta = (_GRAY_INDEX[curr_reading] - _GRAY_INDEX[prev_reading]) % 4
    if delta == 1:
        raw_ticks += 1
    elif delta == 3:
        raw_ticks -= 1
    else:
        return (raw_ticks, curr_reading, last_reported), None  # delta 0/2 - ignore

    reported = int(raw_ticks / DETENT_STEPS)  # truncate toward zero, matches C's `/` on longs
    direction = None
    if reported != last_reported:
        direction = 1 if reported > last_reported else -1
        last_reported = reported
    return (raw_ticks, curr_reading, last_reported), direction


# Time-based debounce: ANY raw edge resets a settle timer, and a reading only
# becomes the new accepted/stable value once the raw signal has been quiet
# (no further edges at all) for the full debounce window. Ported directly from
# a proven-working pattern in a sister project driving the same kind of
# encoder+round-display setup (CubeLED, ESP32) - see
# ../CubeLED/Arduino/V8/V8.ino handleButton(), BTN_DEBOUNCE_MS=30. This is
# stricter than counting N consecutive stable poll() samples: sample-counting
# can still get lucky and accept a short quiet gap *during* an ongoing bounce
# train, while a settle timer that resets on every single edge cannot commit
# until the bouncing has genuinely stopped for the whole window.
#
# Button debounce also structurally guarantees "must release before firing
# again": button_down only fires when the stable value transitions to
# pressed, which requires first passing back through a fully debounced
# "released" stable state - a bounce back to pressed for less than the debounce
# window never reaches "stable", so it can't re-fire early.
BTN_DEBOUNCE_S = 0.03
# A raw, undebounced 2ms-poll capture on real hardware (12.09.2026, see
# NOTES_FOR_PER.md) showed a perfectly clean signal - every click completed
# the full 4-state Gray cycle with zero bounce/reversal - but individual
# intermediate states lasted as little as ~2-3ms. The previous 5ms value
# required 5ms of *quiet* before accepting a reading, which a 2-3ms-lived
# state can never satisfy - it get silently dropped, which is what produced
# the "only half the Gray cycle observed" symptom, not a hardware fault.
# Since there's no real bounce to filter, this only needs to guard against
# an occasional I2C glitch, not genuine switch chatter.
ENC_DEBOUNCE_S = 0.001

# DETENT_STEPS only fixes double-firing on a full click - the boundary
# itself is still exactly 1-tick-sensitive no matter how big DETENT_STEPS
# is, so a real physical overshoot-and-settle-back right at the detent can
# immediately un-cross the boundary it just crossed, reporting the opposite
# direction a few ms later (a genuine live-usage report, not something the
# earlier 2ms raw capture would show - that was a deliberate slow single
# click, not release behavior at natural turning speed). Real distinct
# clicks are always >300ms apart in every capture in NOTES_FOR_PER.md, so a
# generous window here can't eat one; same-direction re-fires don't need
# this at all since DETENT_STEPS=4 already means one click = one report.
ROTATE_OPPOSITE_SUPPRESS_S = 0.03


class ButtonBox:
    def __init__(self, bus=BUS, address=SX1509_ADDR):
        self._bus = SMBus(bus)
        self._addr = address
        self._bus.write_byte_data(self._addr, REG_DIR_A, 0xFF)      # bank A all inputs (POR default anyway)
        self._bus.write_byte_data(self._addr, REG_PULLUP_A, 0x3F)   # pull-ups on I/O0-5

        now = time.monotonic()
        data = self._read_data_a()
        self._button_state = {n: bool(data & (1 << n)) for n in BUTTON_NAMES}  # debounced/stable
        self._button_raw = dict(self._button_state)
        self._button_raw_changed_at = {n: now for n in BUTTON_NAMES}

        enc_reading = ((data >> PIN_ENC_A) & 1) << 1 | ((data >> PIN_ENC_B) & 1)
        self._enc_state = (0, enc_reading, 0)  # (raw_ticks, stable reading, last_reported)
        self._enc_raw = enc_reading
        self._enc_raw_changed_at = now
        self._last_rotate_dir = None
        self._last_rotate_time = None

    def _read_data_a(self):
        return self._bus.read_byte_data(self._addr, REG_DATA_A)

    def poll(self):
        """Read current pin states, return a list of event dicts. Call regularly (e.g. every 5-10ms).
        Encoder states can be as short as ~2-3ms (see ENC_DEBOUNCE_S comment above), so a caller
        needing reliable rotation detection should poll this from a fast background thread instead
        of its own slower loop - see ThreadedPoller below, used by Software/main.py."""
        events = []
        now = time.monotonic()
        data = self._read_data_a()

        for num, name in BUTTON_NAMES.items():
            raw = bool(data & (1 << num))  # True = released (pulled up), False = pressed
            if raw != self._button_raw[num]:
                self._button_raw[num] = raw
                self._button_raw_changed_at[num] = now
            if now - self._button_raw_changed_at[num] < BTN_DEBOUNCE_S:
                continue  # still settling
            if raw == self._button_state[num]:
                continue  # stable value hasn't actually changed
            self._button_state[num] = raw
            events.append({"type": "button_up" if raw else "button_down", "name": name})

        raw_enc = ((data >> PIN_ENC_A) & 1) << 1 | ((data >> PIN_ENC_B) & 1)
        if raw_enc != self._enc_raw:
            self._enc_raw = raw_enc
            self._enc_raw_changed_at = now
        if now - self._enc_raw_changed_at >= ENC_DEBOUNCE_S and raw_enc != self._enc_state[1]:
            prev_reading = self._enc_state[1]
            self._enc_state, direction = decode_encoder_step(self._enc_state, raw_enc)
            print(f"[{now:.3f}] enc raw={data:#04x} pins {prev_reading:02b}->{raw_enc:02b} "
                  f"ticks={self._enc_state[0]} dir={direction}", flush=True)
            if direction:
                just_reversed = (self._last_rotate_time is not None
                                  and direction != self._last_rotate_dir
                                  and now - self._last_rotate_time < ROTATE_OPPOSITE_SUPPRESS_S)
                if not just_reversed:
                    events.append({"type": "rotate", "direction": direction})
                    self._last_rotate_dir = direction
                    self._last_rotate_time = now

        return events


# Encoder states can be as short as ~2-3ms (see ENC_DEBOUNCE_S comment above),
# so whatever calls poll() needs to do so well under that - too fast for
# Software/main.py's 10ms render-loop cadence, which also briefly blocks on
# actual rendering. This wraps any poll()-able object (ButtonBox, but also
# useful for PowerButton) with a background thread that polls it as fast as
# the I2C bus allows; the wrapped poll() just drains the queue the thread
# fills, decoupled from whatever the caller's own loop is busy with.
class ThreadedPoller:
    def __init__(self, target, interval=0.001):
        self._target = target
        self._events = queue.Queue()
        self._thread = threading.Thread(target=self._run, args=(interval,), daemon=True)
        self._thread.start()

    def _run(self, interval):
        while True:
            try:
                for event in self._target.poll():
                    self._events.put(event)
            except OSError as e:
                # Bus-wide I2C glitch (03.10.2026, mid-sync: SX1509 + QMI8658A
                # failed in the same ms) used to kill this thread - buttons
                # dead for the rest of the run. Skip the read, retry next tick.
                print(f"buttonbox: I2C-Lesefehler, ignoriert: {e}", flush=True)
                time.sleep(0.1)  # don't flood the journal if the bus stays down
            time.sleep(interval)

    def poll(self):
        events = []
        while True:
            try:
                events.append(self._events.get_nowait())
            except queue.Empty:
                return events


def demo():
    """Self-check: init the expander and poll for 15s, printing events. Requires real hardware on the I2C bus."""
    box = ThreadedPoller(ButtonBox())
    print("Polling ButtonBox for 15s - press buttons / turn the knob now.")
    end = time.monotonic() + 15
    while time.monotonic() < end:
        for event in box.poll():
            print(event)
        time.sleep(0.02)  # just draining the queue here; the background thread does the real polling


if __name__ == "__main__":
    demo()

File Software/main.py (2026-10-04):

"""Main UI loop for the front display (GC9A01), driven by ButtonBox + QMI8658A."""
import os
import threading
import time

import numpy as np
import board
import digitalio
import fourwire
import displayio
import adafruit_gc9a01a

import player
import ui_state
import ui_render
import connectivity
import sync_youtube
from buttonbox import ButtonBox, ThreadedPoller
from power_button import PowerButton, trigger_shutdown
from settings import Settings
from qmi8658 import QMI8658, orientation, magnitude, SHAKE_THRESHOLD_G
from max17048 import MAX17048
from rt9466 import RT9466
import charge_control

# Real per-frame cost measured on-device: ~83ms (37ms render + 46ms SPI push,
# see journalctl -u mp3player.service). The previous 250ms value was an
# untested guess and throttled the disc animation to a choppy 4fps despite
# the hardware comfortably sustaining ~10fps - set close to the real floor,
# not the old guess.
PLAYING_REDRAW_INTERVAL = 0.1
MOTION_POLL_INTERVAL = 0.1
BT_REDRAW_INTERVAL = 0.5  # catches scan/pair completion without needing a button press
WIFI_REDRAW_INTERVAL = 0.5  # same reasoning, for WifiWorker's scan/connect
WIFI_RESCAN_INTERVAL = 6  # re-scan periodically while sitting on the WLAN list, so a
                          # network that wasn't broadcasting yet (e.g. a phone hotspot
                          # just switched on) shows up without leaving and re-entering
SYNC_REDRAW_INTERVAL = 0.5  # same reasoning - device-flow poll / download progress land via SyncWorker
QUICK_CONNECT_REDRAW_INTERVAL = 0.1  # animates the hold-ring, and catches BTWorker's async "connecting"->"error" -
                                      # the success case is already caught by the state.screen change below
BATTERY_POLL_INTERVAL = 30  # SOC changes slowly - no reason to hit I2C more often
ETA_CALC_INTERVAL = 60  # remaining-runtime estimate: recompute/smooth at most once a minute
ETA_SMOOTHING = 0.3  # EMA weight for the newest sample - low so the estimate doesn't jump around
STATUS_POLL_INTERVAL = 10  # WLAN/BT "connected" check - cheap nmcli/bluetoothctl queries, no scan involved
WIFI_AUTO_OFF_S = 180  # turn WiFi radio off after this long without a button/encoder event


def init_display():
    displayio.release_displays()
    backlight = digitalio.DigitalInOut(board.D13)
    backlight.direction = digitalio.Direction.OUTPUT
    backlight.value = True
    spi = board.SPI()
    display_bus = fourwire.FourWire(
        spi, command=board.D24, chip_select=board.CE0, reset=board.D25, baudrate=24000000
    )
    # adafruit_gc9a01a.GC9A01A(...) runs the chip's power-on/gamma/sleep-out/
    # COLMOD/MADCTL init sequence over display_bus - that's the only thing it's
    # still used for below (see FrameSink). Keep the returned object alive so
    # it isn't garbage-collected/released, even though nothing reads its
    # root_group after this.
    # auto_refresh=False: Blinka's displayio starts a daemon thread at import time
    # that re-composes and pushes each registered display's root group over this
    # same SPI bus/CS/DC. FrameSink.push() writes from the main thread with no
    # lock, so with the default auto_refresh=True the two can interleave raw SPI
    # transactions (the first full refresh of the empty splash group takes
    # ~700-900ms in pure Python, right when the first real frame lands at boot).
    display = adafruit_gc9a01a.GC9A01A(display_bus, width=240, height=240, auto_refresh=False)
    return display_bus, display, backlight


CMD_CASET = 0x2A  # column address set
CMD_RASET = 0x2B  # row address set
CMD_RAMWR = 0x2C  # memory write


class FrameSink:
    """Pushes rendered PIL frames straight to the display over SPI, bypassing
    displayio's Bitmap/TileGrid/ColorConverter machinery entirely.

    History (see NOTES_FOR_PER.md): the old OnDiskBitmap path re-read every pixel
    from disk each frame (~700-900ms/frame). Moving to an in-RAM Bitmap written
    pixel-by-pixel via bitmap[i]=value was STILL ~700-900ms/frame, because
    Bitmap.__setitem__ allocates a fresh Area() and recomputes the dirty rect on
    every single call. A bulk buffer write into the Bitmap fixed THAT (down to a
    few ms) - but displayio still has to walk the whole dirty bitmap pixel-by-pixel
    in pure Python (TileGrid._fill_area(), confirmed in Adafruit_Blinka_Displayio's
    source) to compose it back out over SPI on every refresh. That's a second,
    separate slow Python loop inside displayio itself, unavoidable as long as
    anything goes through Bitmap/TileGrid/Group.

    Real fix: skip displayio's composition layer completely. FourWire.send(command,
    data) is a public method (confirmed in the installed fourwire package) that
    does a raw SPI command+data transfer with correct CS/DC handling - exactly
    what a bare-metal/Arduino GC9A01 driver does. Standard MIPI DBI command set
    (same numbering as ILI9341/ST7789/GC9A01): 0x2A/0x2B set the column/row
    address window, 0x2C streams raw pixel bytes into it. The chip is already
    configured for RGB565 by adafruit_gc9a01a's init sequence, so this only
    needs to send bytes - no separate reinit.
    """

    def __init__(self, display_bus, width=240, height=240):
        self.bus = display_bus
        self.width = width
        self.height = height
        self._caset = bytes([0, 0, (width - 1) >> 8, (width - 1) & 0xFF])
        self._raset = bytes([0, 0, (height - 1) >> 8, (height - 1) & 0xFF])

    def push(self, img):
        arr = np.asarray(img.convert("RGB"), dtype=np.uint16)
        rgb565 = (((arr[..., 0] & 0xF8) << 8) | ((arr[..., 1] & 0xFC) << 3) | (arr[..., 2] >> 3))
        # Big-endian (MSB first) on the wire - standard for this display family.
        # If colors come out wrong (swapped/garbled, as opposed to just a plain
        # wrong hue), switch this to "<u2" instead.
        pixel_bytes = rgb565.astype(">u2").tobytes()
        self.bus.send(CMD_CASET, self._caset)
        self.bus.send(CMD_RASET, self._raset)
        self.bus.send(CMD_RAMWR, pixel_bytes)
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

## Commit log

2026-08-18 Inital Commit
    Uploaded KiCad Files for PCB Manifacturing
    [AUDIO-SMD_L11.8-W6.0-H5.0-4P.step, ButtonBox.kicad_pcb, ButtonBox.kicad_sch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]
2026-08-18 uploaded Gerber Zips
2026-08-18 added STL for stencil
    [ButtonBox.stl, Main.stl]
2026-09-10 lol idk
    [Projekt 1.csv, Projekt 1.kicad_pcb]
2026-09-16 Add design spec for home-status-ring (battery + WLAN/BT indicator)
    Brainstormed and approved layout for a battery/WLAN/Bluetooth status
    ring hugging the round display's outer bezel margin.
2026-09-16 Fix WLAN connect/scan/forget failing with "No Permission" in the UI
    NetworkManager's network-control and wifi.scan permissions are "auth"
    (not "no"), meaning polkit would normally prompt - but there's no polkit
    agent in the headless SSH/systemd session mp3player.service runs under, so
    every connect/rescan/disconnect/forget failed outright. Extends the same
    sudo -n pattern already used for the WLAN radio on/off toggle to the rest
    of connectivity.py's nmcli calls, paired with a scoped NOPASSWD sudoers
    rule for exactly those subcommands (/etc/sudoers.d/mp3player-network on
    the device, not tracked in this repo).
    [connectivity.py]
2026-10-04 added 3d Model and removed stencil stl's
    [ButtonBox.stl, Main.stl]
2026-10-12 Add NOPASSWD sudoers rule for nmcli WiFi control to setup_pi.sh
    connectivity.py runs all WiFi radio/connection changes via `sudo -n nmcli`,
    but setup_pi.sh only installed the poweroff rule - after WiFi auto-off the
    UI could not re-enable it ("sudo: a password is required").
2026-10-12 Add design spec for switchable UI themes (8 designs incl. Pixelhaus)
2026-10-12 Add implementation plan for switchable UI themes
2026-10-12 Add ui_views: screen content as plain view data for switchable designs
2026-10-12 Move renderer into themes/klassik behind a view-based ui_render facade
    Klassik verified pixel-identical against 439 baseline frames except the
    planned 'Suche Netzwerke...' y 106->110 normalization (5 frames, one per
    UI scale).
2026-10-12 Bundle OFL fonts and add the shared design toolkit + edge-case contract test
    Fonts from github.com/google/fonts (OFL, license files alongside), download
    approved by Per on 12.10.2026.
2026-10-12 Add Cybercore design
    Also speeds up the shared design toolkit: cached ring-band masks (one paste
    instead of ~30 full-frame pieslice pastes per frame) and cached text width /
    text masks (the hinted bundled fonts cost up to ~1.7 ms per rendered line).
2026-10-12 Add Pixelhaus design: rooms in a pixel-art house with a floating camera
    assets/pixelhaus.png is Per's house image (1536x1024), used 1:1.
2026-10-12 Document switchable designs
2026-10-12 Review fixes: Pixelhaus keeps its menu while scrolling, tests reach its dialog code
    - Pixelhaus: the camera drift on Home/Werkstatt (and short pans like
    Bibliothek -> Regal) no longer hides the dialog box; only flights to
    another room do.
    - Walk and edge-case contract tests use an instant camera so Pixelhaus'
    dialog drawing code is actually exercised (asserted per edge view).
    - Neumorph: the WLAN-password retry hint fits again at every UI scale
    (new cross-design test).
    - CLAUDE.md: themes/, ui_views.py and ui_common.py are required on deploy.
